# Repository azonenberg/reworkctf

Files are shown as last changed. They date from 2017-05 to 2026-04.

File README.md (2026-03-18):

# reworkctf

## What is it?

This is a points-based challenge board intended for practicing of PCB rework and circuit editing skills. This is not a circuit *debug* challenge. The defect for each stage is well documented, your task is to correct it so that the circuit functions properly.

This is also not a learn-to-solder kit. If you're not comfortable populating boards with 0402 passives and larger pitch (0.8mm) BGAs, this is probably not a project you want to undertake until you have the basics down first.

That said, the challenges range from very easy to fairly difficult, so it's totally fine to try some of them then put the board on a shelf for a while until your skills improve. Inner layer circuit edits are among the most challenging rework tasks around, there's a reason they're worth the most points!

This is also intended to be a relatively low-cost board so you can practice without the pressure of reworking a production design with a big FPGA and five-digit price tag. If you destroy a couple of these boards then get the hang of things and your third attempt succeeds, great - you've learned something.

And if the board survives, you've got a STM32H750 dev platform with a UART, two PMODs, a SPI flash, and a lot of LEDs to maybe do something useful with.

IMPORTANT NOTE: Read the challenge list before populating the front side of the PCB. Some of the BGA-site challenges have two versions, an "easy" version which can be done on a bare PCB before populating allowing easy access to the BGA footprint, and a "hard" version which requires you populate the board before doing the rework. Unless you want to do the hard version twice, don't populate the board until you've done the easier ones. This does require doing some of the challenges out of order, unless you want to make two boards and do different challenges on each.

Most notably, the following challenges should be done before populating the BGA:
* Challenge 13

## How do I complete a given challenge?

It's up to you, within reason. If you are able to restore the intended electrical connectivity to the point that the firmware lights up the corresponding "complete" LED and you've followed any restrictions listed in the problem text, you've done it. Please follow the spirit of the challenges, many of them can be "cheated" by jumpering adjacent pins on the MCU together or similar but the point of this board is skill development. If you don't actually fix the intended defect you're not learning.

Almost all challenges are electrically testable by the MCU firmware; those that involve soldermask or silkscreen rework can be graded by visual inspection of the board. If those look good, they probably are.

The [IPC rework guides](https://www.circuitrework.com/guides/guides.html) are a good starting point for general repair techniques.

If you get really stuck on a specific challenge you can message me on Mastodon at[@azonenberg@ioc.exchange](https://ioc.exchange/@azonenberg]) but please make a reasonable attempt to plan a solution first.

## I still have an old rev board, where's the info for that?

The legacy revision 1 challenge, built around a Spartan-3A FPGA, can be found in the "v1" directory and is being kept there in case anybody has an old board and wants to refer to the design. Anyone building the challenge now should use the v2 design which is based on parts that (as of this writing in early 2026) are readily available and inexpensive.

## What tools are required?

A fine point soldering iron, good tweezers, and hot air rework station are a must to attempt any of the challenges. A stereo microscope is strongly recommended.

The silkscreen and solder mask repair challenges require UV or heat cured coating materials and a curing lamp or oven appropriate for the coating chemistry. UV resin allows much more rapid iteration and avoids heat stress on the remainder of the system so we strongly recommend it over heat cure systems.

Surface trace cuts and rerouting require a scalpel or rotary tool/mill with very fine cutters. While the inner layer circuit edits are *possible* to complete with hand scraping or a handheld rotary tool, we strongly recommend use of a 3-axis mill and microscope for the highest grade results and greatest chance of success.

## What are the challenges?

See [the list here](/CHALLENGES.md). Each challenge is marked with silkscreened text on the PCB to make it easy to find.

## What is the "Free Play Area"?

A big pile of component footprints and traces not connected to anything else. Invent your own challenges or use it to practice for the official ones.

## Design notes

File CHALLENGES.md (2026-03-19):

# ReworkCTF challenge list

## Silkscreen / Solder Mask

These challenges are not electronically gradeable, so they're numbered separately from the others (with a SM- prefix).

### SM-1 (100 points)

Oops, we forgot to label the debug connector! Mark it "JTAG" in white ink.

### SM-2 (100 points)

There's a big hole in the soldermask on the back of the board. Don't ask how it got there, just fix it.

## Surface Conductor

### Challenge 01 (100 points)

A dust speck landed on a photomask and caused a small dot of copper to short the signal trace to the adjacent ground. Clear the short.

### Challenge 02 (200 points)

An etch defect caused two signal traces to short to each other. Clear the short.

### Challenge 08 (100 points)

Somebody dropped a heavy tool on the board and gouged out a short segment from a trace. Reconnect the missing piece.

## Multilayer Conductor / Via

### Challenge 09 (400 points)

We swapped a differential pair for easier layout and didn't realize the SERDES macro didn't have a polarity swap bit. If that wasn't bad enough, it's on an internal layer.

Swap the pair.

(You must do an inner layer circuit edit for this problem. The BGA breakout traces and vias are out of scope.)

### Challenge 10 (300 points)

Somehow we forgot a via between the top and bottom layer. Restore the connection.

### Challenge 11 (400 points)

A zone fill got screwed up and a via from front to back is shorted to the power plane. Clear the short but preserve the intended connection.

(You must do an inner layer circuit edit for this problem, bypassing the via or isolating the zone fill is not allowed.)

### Challenge 15 (100 points)

Somebody forgot a pullup on an open-drain signal. Add a 10K resistor from the trace to the 3V3 rail.

## SMT Component

### Challenge 03 (100 points)

Whoops, one of the LEDs was put on with reversed polarity. Flip it.

### Challenge 04 (200 points)

Place an 10K ohm 0201 resistor on the provided footprint.

### Challenge 05 (300 points)

Place an 10K ohm 01005 resistor on the provided footprint.

### Challenge 06 (200 points)

The intern who made our SOIC flash footprint forgot to put a soldermask aperture on one of the pins! Remove the component, clear the soldermask off the pad, and reconnect the flash.

NOTE: The challenge 6 status LED will not illuminate unless challenge 7 has also been completed.

### Challenge 07 (300 points)

While our previous technician was doing challenge 6, they got too aggressive desoldering and lifted a pad. Install a new pad on the board and restore connectivity to the pin.

NOTE: The challenge 7 status LED will not illuminate unless challenge 6 has also been completed.

## BGA

### Challenge 12 (300 points)

Our solder paste is expired and two balls didn't get good paste coverage so they're not making good contact. Fix it.

(A test point is provided to allow electrical measurements of the test signal)

### Challenge 13 (400 points)

Our BGA breakout generator script had a bug and one of the BGA breakout vias is missing a dogbone trace. Luckily, we discovered the problem BEFORE populating the board, so you have easy access to the BGA site.

### Challenge 14 (500 points)

This is the same exact defect as challenge 13, except somehow it went unnoticed until the board was populated. Have fun.

### Challenge 16 (500 points)

Pin R16 of the MCU should have been strapped to 3V3 but was instead connected to ground. Reconnect the via to the correct plane.

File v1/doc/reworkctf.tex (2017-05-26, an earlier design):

\documentclass{article}
\usepackage[bookmarks,colorlinks=true,linkcolor=blue,urlcolor=blue]{hyperref}
\usepackage{url}
\usepackage{tabularx}
\usepackage{graphicx}
\usepackage{placeins}

\setcounter{tocdepth}{2}

\begin{document}

\title{\vspace*{\fill}PCB Rework CTF}
\author{Andrew Zonenberg\\
azonenberg@drawersteak.com}
\date{\today}

\maketitle
\begin{abstract}
The ``Rework CTF" is a game/training aid, similar to an infosec challenge-based CTF, but focusing on PCB rework and
soldering skills. The intended focus is on technician skills (fixing defects) not engineering skills (finding defects).
The game is intended to be played on fully populated boards; the provided FPGA bitstream will automatically grade most
problems and light up an LED upon successful completion. Additional blank boards may be used for practice and
instruction before a for-point challenge is attempted on a populated PCB.
\end{abstract}
\thispagestyle{empty}

\pagebreak

\tableofcontents

\pagebreak
\section{Introduction}

The bugs are sorted by difficulty, ranging from 100 to 500 points. Any and all tools are in scope, however cheating by
simply shorting the LEVELx\_OK signal to power is not allowed. Specific rules, if applicable, are described in the
subsections for each bug.

Signals related to each bug are prefixed with ``LEVELx\_" in the KiCAD design files to make the bugs easier to find.

There are two kinds of bugs in this board. Electrical connectivity bugs have numeric level identifiers (1, 2, 3, etc).
The corresponding LED will light up when these problems are successfully completed. Mechanical/visual bugs have
alphabetical level identifiers (A, B, C, etc). These are graded by looking at the board and deciding if it looks OK.

All design files, including the Verilog source for the grader bitstream, are available under a 3-clause BSD-style
license.

\pagebreak
\section{100-Point Bugs}

\subsection{Level 1}

Input to a SOIC-packaged 7404 is shorted to the adjacent Vdd. Clear the short.

\subsection{Level 2}

LED-drive enable is always high, but the LED itself was installed backwards, Use hot air to flip it around.

\subsection{Level 3}

Input pad on a SOIC-packaged 7404 footprint is missing. Restore the open connection and install the IC. (50 bonus
points for style if you put in a new SMT pad rather than just running a jumper.)

\subsection{Level 4}

0805 resistor is missing soldermask apertures. Remove the mask and solder a low-valued (anything under 1K should be fine)
resistor onto the pads.

\subsection{Level A}

The resistor you installed in level 4 doesn't have a refdes. Label it ``R30" with white ink.

\subsection{Level B}

A region of the board is missing some solder mask. Mix up some 2-part epoxy, tint it to match the existing mask, and
brush it on.

\pagebreak
\section{200-Point Bugs}

\subsection{Level 5}

Tiny short circuit between two closely spaced signals. Clear the short without damaging either line.

\subsection{Level 6}

Large short circuit between two closely spaced signals. Clear the short without damaging either line.

\subsection{Level 7}

LVDS pair on outer layer with P/N swapped. Hook them up correctly.

\subsection{Level 8}

Several pads on a TSSOP-packaged 7404 footprint are missing. Restore the open connection and install the IC. (50
bonus points for style if you put in a new SMT pad rather than just running a jumper.)

\subsection{Level 9}

Install an 01005 resistor (anything under 1K should be fine) onto the provided pads.

\subsection{Level 10}

Via connecting to input of TSSOP-packaged 7404 doesn't actually connect to the input. Fix it.

\subsection{Level 11}

Missing thermal relief connecting to one side of an 0201 passive causing tombstoning. Cut out a thermal relief and fix
the tombstoned part.

\pagebreak
\section{300-Point Bugs}

\subsection{Level 12}

A through-board via wasn't drilled. Fix it.

\subsection{Level 13}

Two signals on an internal layer are shorted. Clear the short.

\subsection{Level 14}

A dogbone via on the FPGA footprint wasn't connected to the corresponding ball. Fix it before installing the FPGA.

\pagebreak
\section{400-Point Bugs}

\subsection{Level 15}

A differential pair on an internal layer is swapped. Fix it. For this level, you're not allowed to just drill out the
trace and connect the vias directly, we're pretending the vias are blind/buried. You must fix this with an inner-layer
circuit edit.

\subsection{Level 16}

Two signals on an internal layer are shorted together. Clear the short. Heavy routing congestion on the top layer
make this harder than level 13.

\subsection{Level 17}

Due to a drill-gerber file version mismatch, a signal via was shorted to the internal ground plane. Clear the short.

\subsection{Level 18}

A dogbone via on the FPGA footprint wasn't drilled out. Fix it before installing the FPGA.

\pagebreak
\section{500-Point Bugs}

\subsection{Level 19}

Two blind vias at the same place on opposite sides of the board were incorrectly drilled as a through-board via.
Separate the two vias so that the outer layers connect to the adjacent plane, but they don't short to each other.

\subsection{Level 20}

A strap pin under a BGA was incorrectly tied high. Pull it low instead.

\subsection{Level 21}

Two signals on an internal layer are shorted together. Clear the short. Heavy routing congestion on both outer layers
make this harder than level 16.

\subsection{Level 22}

A dogbone via on the FPGA footprint wasn't drilled out. Fix it after installing the FPGA.

\subsection{Level 23}

I put 22 intentional bugs in this board. Can you find a 23rd? If so, there's a spot marked for you to install another
LED. You've earned it!

\pagebreak
\section{Extra-credit problems}

\subsection{Level 24}

Put a TSSOP-packaged 74HC04 onto the SOIC footprint, or vice versa.

\subsection{TODOs for next version}

TODOs for next version: mirrored IC footprints, holes too small for PTH component

\end{document}

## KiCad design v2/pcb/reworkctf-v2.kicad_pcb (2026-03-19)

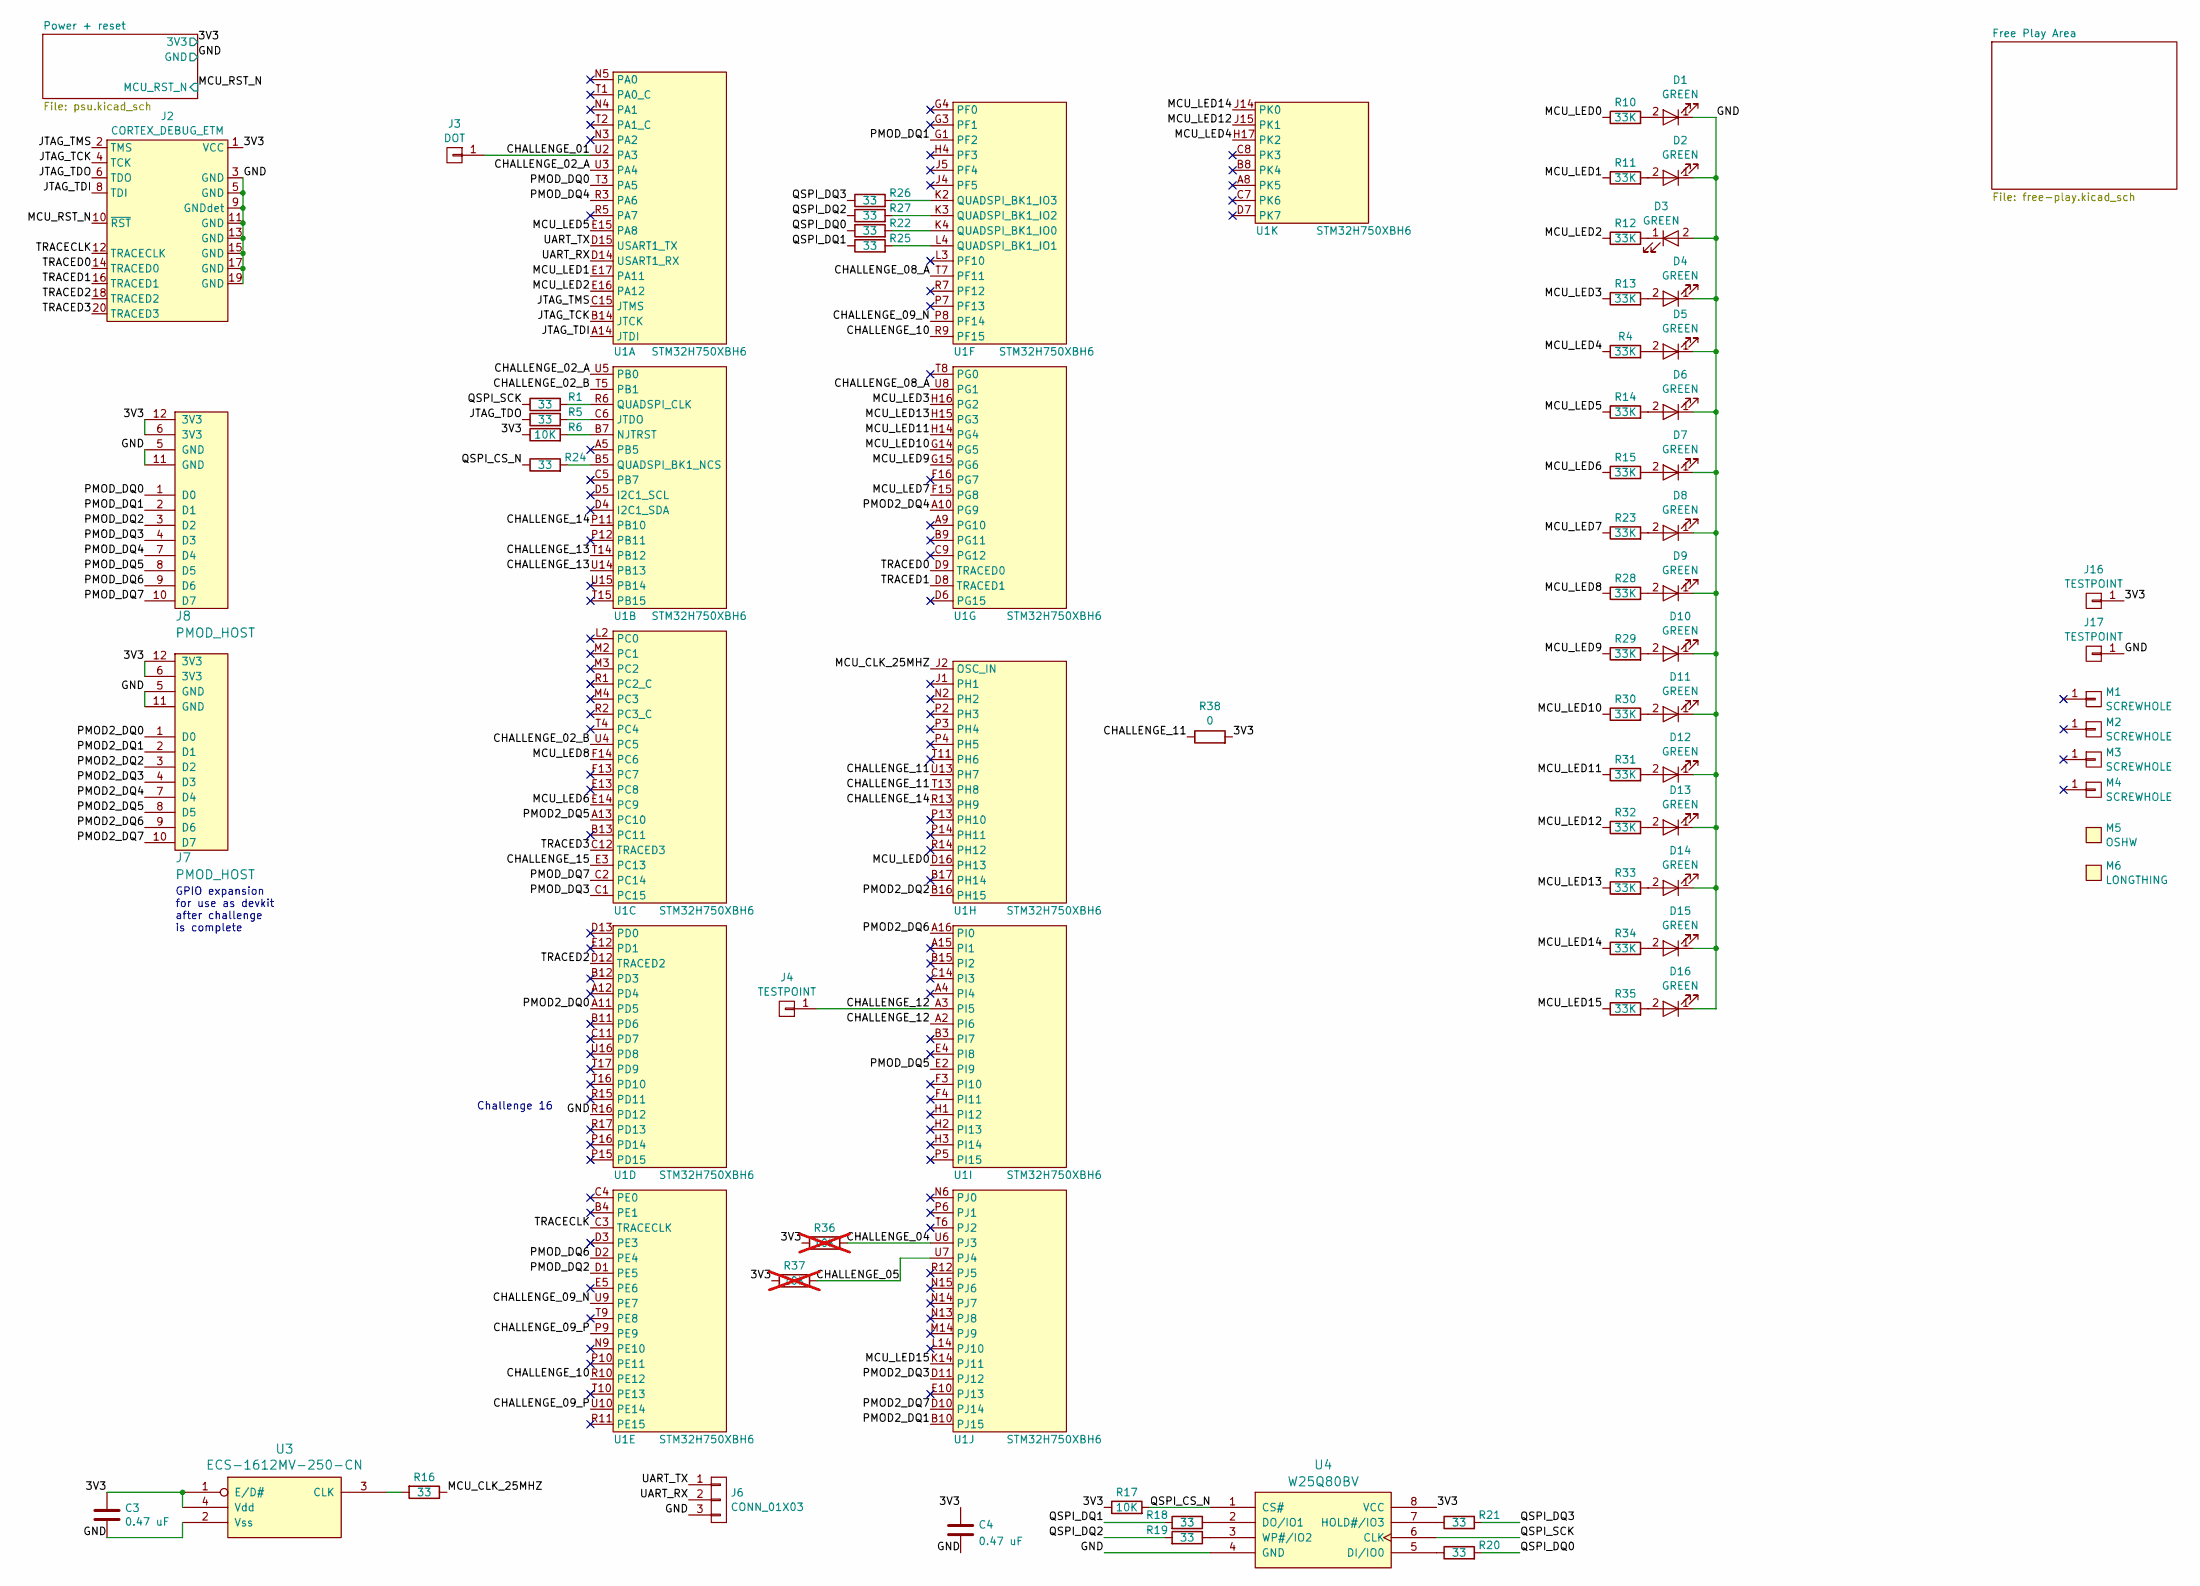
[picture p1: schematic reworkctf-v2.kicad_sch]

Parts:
C3, C4: 0.47 uF; EIA_0402_CAP_NOSILK
D1, D2, D3, D4, D5, D6, D7, D8, D9, D10, D11, D12, D13, D14, D15, D16: GREEN; EIA_0402_LED
J2: CORTEX_DEBUG_ETM; CONN_HEADER_1.27MM_2x10_SMT_SAMTEC_FTSH-110-01-L-DV-K
J3: DOT; TESTPOINT_SMT_0.5MM
J4, J16, J17: TESTPOINT; TESTPOINT_SMT_0.5MM
J6: CONN_01X03; CONN_HEADER_2.54MM_1x3_REFLOW
J7, J8: PMOD_HOST; CONN_HEADER_2.54MM_2x6_RA_PMOD_HOST
M1, M2, M3, M4: SCREWHOLE; MECHANICAL_CLEARANCEHOLE_4_40
M5: OSHW; Logo_silk_OSHW_6x6mm
M6: LONGTHING; LONGTHING-1200DPI
R1, R5, R16, R18, R19, R20, R21, R22, R24, R25, R26, R27: 33; EIA_0402_RES_NOSILK
R4, R10, R11, R12, R13, R14, R15, R23, R28, R29, R30, R31, R32, R33, R34, R35: 33K; EIA_0402_RES_NOSILK
R6, R17: 10K; EIA_0402_RES_NOSILK
R36: 10K; EIA_0201_RES_NOSILK; not fitted
R37: 10K; EIA_01005_RES_NOSILK; not fitted
R38: 0; EIA_0402_RES_NOSILK
U1: STM32H750XBH6; BGA_265_14x14_DEPOP_0.8MM
U3: ECS-1612MV-250-CN; OSCILLATOR_1.6x1.2
U4: W25Q80BV; SOIC_8_5.3MM

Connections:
/3V3: C3.1, C4.1, J2.1 (VCC), J7.6 (3V3), J7.12 (3V3), J8.6 (3V3), J8.12 (3V3), J16.1, R6.1, R17.1, R36.1, R37.1, R38.2, U3.1 (E/D#), U3.4 (Vdd), U4.8 (VCC); also elsewhere on the board
/CHALLENGE_01: J3.1, U1.U2 (PA3)
/CHALLENGE_02_A: U1.U3 (PA4), U1.U5 (PB0)
/CHALLENGE_02_B: U1.T5 (PB1), U1.U4 (PC5)
/CHALLENGE_04: R36.2, U1.U6 (PJ3)
/CHALLENGE_05: R37.2, U1.U7 (PJ4)
/CHALLENGE_08_A: U1.T7 (PF11), U1.U8 (PG1)
/CHALLENGE_09_N: U1.P8 (PF14), U1.U9 (PE7)
/CHALLENGE_09_P: U1.P9 (PE9), U1.U10 (PE14)
/CHALLENGE_10: U1.R9 (PF15), U1.R10 (PE12)
/CHALLENGE_11: R38.1, U1.T13 (PH8), U1.U13 (PH7)
/CHALLENGE_12: J4.1, U1.A2 (PI6), U1.A3 (PI5)
/CHALLENGE_13: U1.T14 (PB12), U1.U14 (PB13)
/CHALLENGE_14: U1.P11 (PB10), U1.R13 (PH9)
/CHALLENGE_15: U1.E3 (PC13)
/GND: C3.2, C4.2, D1.1 (K), D2.1 (K), D3.2 (A), D4.1 (K), D5.1 (K), D6.1 (K), D7.1 (K), D8.1 (K), D9.1 (K), D10.1 (K), D11.1 (K), D12.1 (K), D13.1 (K), D14.1 (K), D15.1 (K), D16.1 (K), J2.3 (GND), J2.5 (GND), J2.9 (GNDdet), J2.11 (GND), J2.13 (GND), J2.15 (GND), J2.17 (GND), J2.19 (GND), J6.3, J7.5 (GND), J7.11 (GND), J8.5 (GND), J8.11 (GND), J17.1, U1.R16 (PD12), U3.2 (Vss), U4.4 (GND); also elsewhere on the board
/JTAG_TCK: J2.4 (TCK), U1.B14 (JTCK)
/JTAG_TDI: J2.8 (TDI), U1.A14 (JTDI)
/JTAG_TDO: J2.6 (TDO), R5.1
/JTAG_TMS: J2.2 (TMS), U1.C15 (JTMS)
/MCU_CLK_25MHZ: R16.1, U1.J2 (OSC_IN)
/MCU_LED0: R10.1, U1.D16 (PH13)
/MCU_LED1: R11.1, U1.E17 (PA11)
/MCU_LED2: R12.1, U1.E16 (PA12)
/MCU_LED3: R13.1, U1.H16 (PG2)
/MCU_LED4: R4.1, U1.H17 (PK2)
/MCU_LED5: R14.1, U1.E15 (PA8)
/MCU_LED6: R15.1, U1.E14 (PC9)
/MCU_LED7: R23.1, U1.F15 (PG8)
/MCU_LED8: R28.1, U1.F14 (PC6)
/MCU_LED9: R29.1, U1.G15 (PG6)
/MCU_LED10: R30.1, U1.G14 (PG5)
/MCU_LED11: R31.1, U1.H14 (PG4)
/MCU_LED12: R32.1, U1.J15 (PK1)
/MCU_LED13: R33.1, U1.H15 (PG3)
/MCU_LED14: R34.1, U1.J14 (PK0)
/MCU_LED15: R35.1, U1.K14 (PJ11)
/MCU_RST_N: J2.10 (~RST); also elsewhere on the board
/PMOD2_DQ0: J7.1 (D0), U1.A11 (PD5)
/PMOD2_DQ1: J7.2 (D1), U1.B10 (PJ15)
/PMOD2_DQ2: J7.3 (D2), U1.B16 (PH15)
/PMOD2_DQ3: J7.4 (D3), U1.D11 (PJ12)
/PMOD2_DQ4: J7.7 (D4), U1.A10 (PG9)
/PMOD2_DQ5: J7.8 (D5), U1.A13 (PC10)
/PMOD2_DQ6: J7.9 (D6), U1.A16 (PI0)
/PMOD2_DQ7: J7.10 (D7), U1.D10 (PJ14)
/PMOD_DQ0: J8.1 (D0), U1.T3 (PA5)
/PMOD_DQ1: J8.2 (D1), U1.G1 (PF2)
/PMOD_DQ2: J8.3 (D2), U1.D1 (PE5)
/PMOD_DQ3: J8.4 (D3), U1.C1 (PC15)
/PMOD_DQ4: J8.7 (D4), U1.R3 (PA6)
/PMOD_DQ5: J8.8 (D5), U1.E2 (PI9)
/PMOD_DQ6: J8.9 (D6), U1.D2 (PE4)
/PMOD_DQ7: J8.10 (D7), U1.C2 (PC14)
/QSPI_CS_N: R17.2, R24.1, U4.1 (CS#)
/QSPI_DQ0: R20.2, R22.1
/QSPI_DQ1: R18.2, R25.1
/QSPI_DQ2: R19.2, R27.1
/QSPI_DQ3: R21.2, R26.1
/QSPI_SCK: R1.1, U4.6 (CLK)
/TRACECLK: J2.12 (TRACECLK), U1.C3 (TRACECLK)
/TRACED0: J2.14 (TRACED0), U1.D9 (TRACED0)
/TRACED1: J2.16 (TRACED1), U1.D8 (TRACED1)
/TRACED2: J2.18 (TRACED2), U1.D12 (TRACED2)
/TRACED3: J2.20 (TRACED3), U1.C12 (TRACED3)
/UART_RX: J6.2, U1.D14 (USART1_RX)
/UART_TX: J6.1, U1.D15 (USART1_TX)
unnamed: D1.2 (A), R10.2
unnamed: D2.2 (A), R11.2
unnamed: D3.1 (K), R12.2
unnamed: D4.2 (A), R13.2
unnamed: D5.2 (A), R4.2
unnamed: D6.2 (A), R14.2
unnamed: D7.2 (A), R15.2
unnamed: D8.2 (A), R23.2
unnamed: D9.2 (A), R28.2
unnamed: D10.2 (A), R29.2
unnamed: D11.2 (A), R30.2
unnamed: D12.2 (A), R31.2
unnamed: D13.2 (A), R32.2
unnamed: D14.2 (A), R33.2
unnamed: D15.2 (A), R34.2
unnamed: D16.2 (A), R35.2
unnamed: R1.2, U1.R6 (QUADSPI_CLK)
unnamed: R5.2, U1.C6 (JTDO)
unnamed: R6.2, U1.B7 (NJTRST)
unnamed: R24.2, U1.B5 (QUADSPI_BK1_NCS)
unnamed: R26.2, U1.K2 (QUADSPI_BK1_IO3)
unnamed: R27.2, U1.K3 (QUADSPI_BK1_IO2)
unnamed: R22.2, U1.K4 (QUADSPI_BK1_IO0)
unnamed: R25.2, U1.L4 (QUADSPI_BK1_IO1)
unnamed: R16.2, U3.3 (CLK)
unnamed: R20.1, U4.5 (DI/IO0)
unnamed: R18.1, U4.2 (DO/IO1)
unnamed: R21.1, U4.7 (HOLD#/IO3)
unnamed: R19.1, U4.3 (WP#/IO2)

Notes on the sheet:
Challenge 16
GPIO expansion for use as devkit after challenge is complete

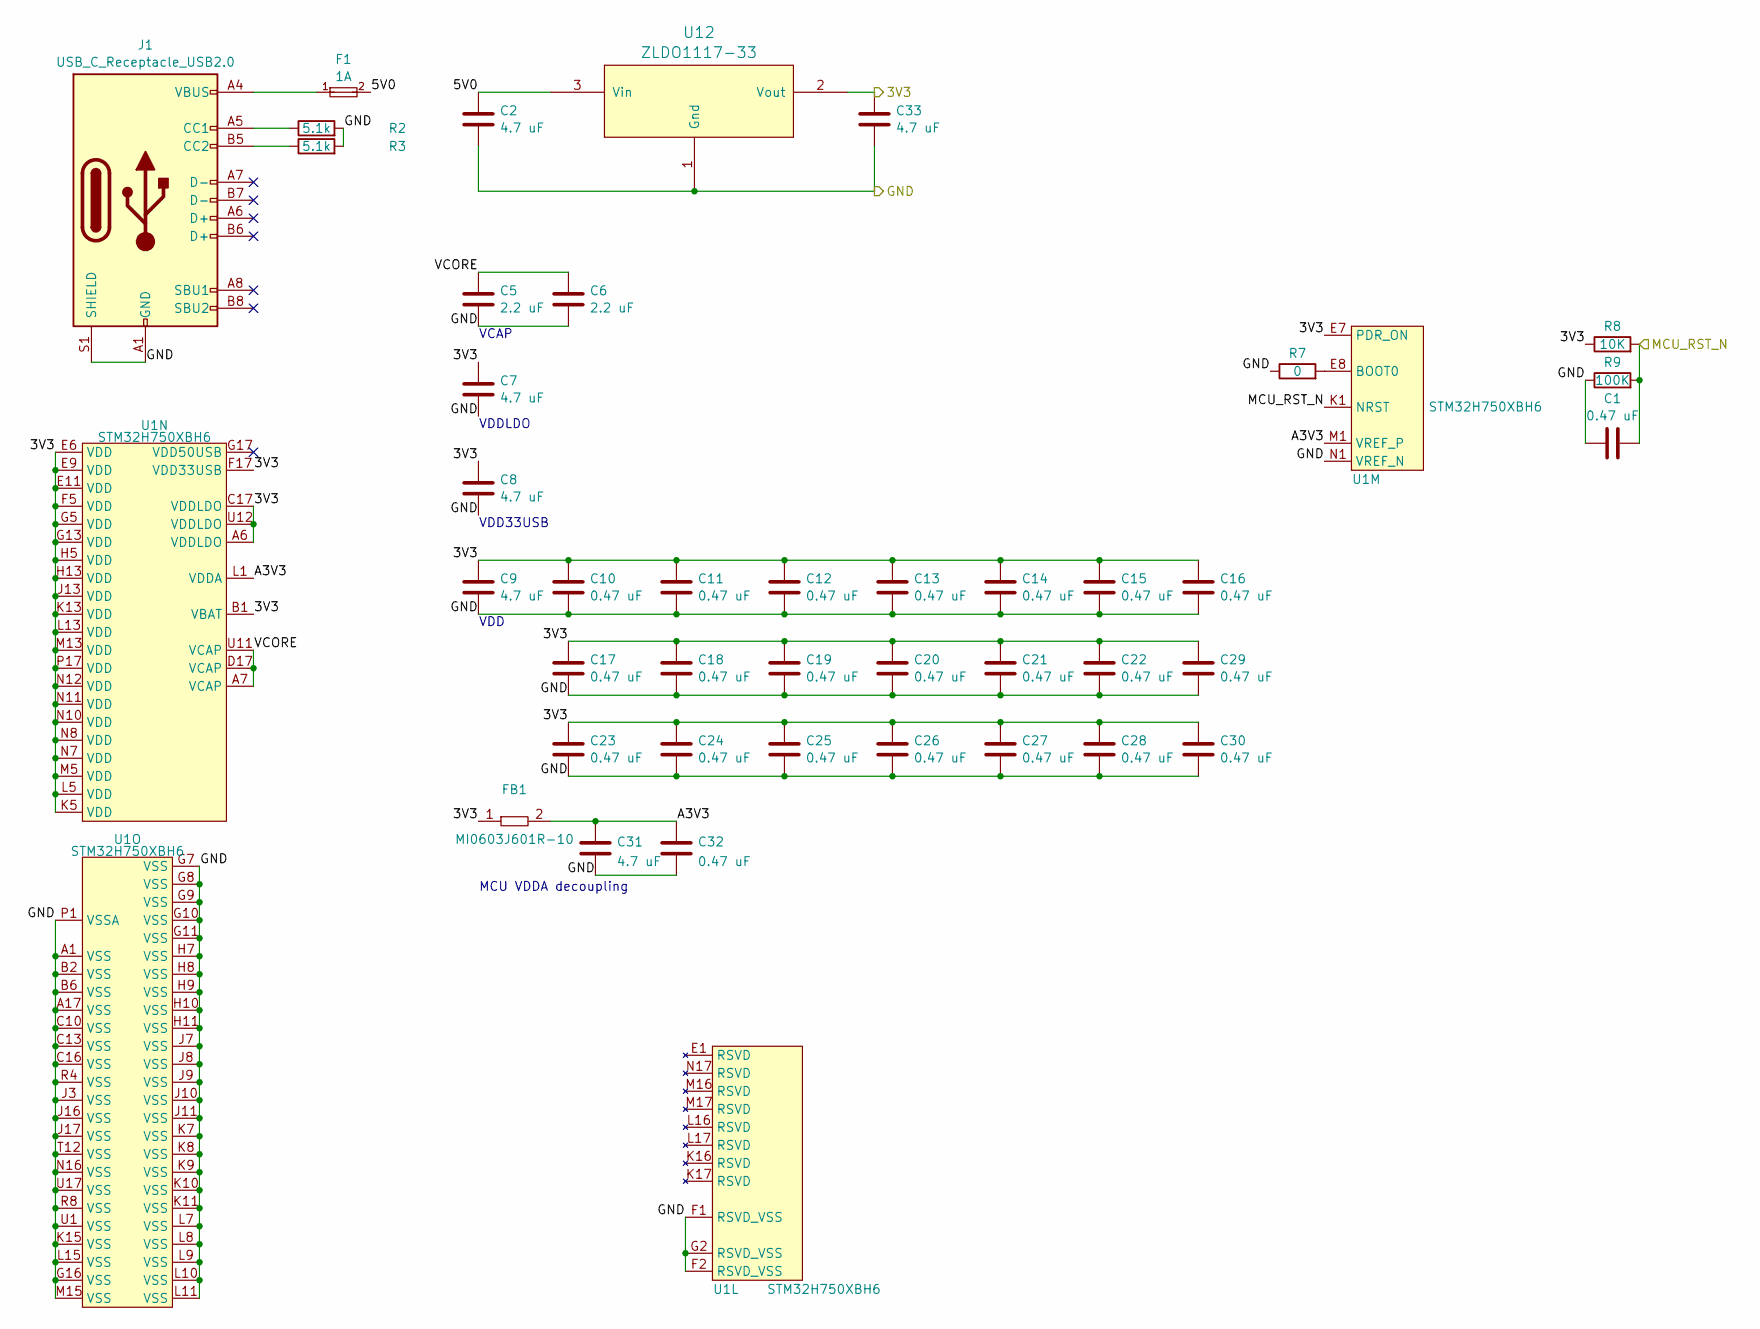
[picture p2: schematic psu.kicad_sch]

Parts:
C1, C10, C11, C12, C13, C14, C15, C16, C17, C18, C19, C20, C21, C22, C23, C24, C25, C26, C27, C28, C29, C30, C32: 0.47 uF; EIA_0402_CAP_NOSILK
C2, C7, C8, C9, C31, C33: 4.7 uF; EIA_0603_CAP_NOSILK
C5, C6: 2.2 uF; EIA_0603_CAP_NOSILK
F1: 1A; EIA_0402_RES_NOSILK
FB1: MI0603J601R-10; EIA_0603_INDUCTOR_NOSILK
J1: USB_C_Receptacle_USB2.0; GCT_USB4500-03-0-A
R2, R3: 5.1k; EIA_0402_RES_NOSILK
R7: 0; EIA_0402_RES_NOSILK
R8: 10K; EIA_0402_RES_NOSILK
R9: 100K; EIA_0402_RES_NOSILK
U1: STM32H750XBH6; BGA_265_14x14_DEPOP_0.8MM
U12: ZLDO1117-33; SOT223-4

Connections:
/3V3: C7.1, C8.1, C9.1, C10.1, C11.1, C12.1, C13.1, C14.1, C15.1, C16.1, C17.1, C18.1, C19.1, C20.1, C21.1, C22.1, C23.1, C24.1, C25.1, C26.1, C27.1, C28.1, C29.1, C30.1, C33.1, FB1.1, R8.1, U1.A6 (VDDLDO), U1.B1 (VBAT), U1.C17 (VDDLDO), U1.E6 (VDD), U1.E7 (PDR_ON), U1.E9 (VDD), U1.E11 (VDD), U1.F5 (VDD), U1.F17 (VDD33USB), U1.G5 (VDD), U1.G13 (VDD), U1.H5 (VDD), U1.H13 (VDD), U1.J13 (VDD), U1.K5 (VDD), U1.K13 (VDD), U1.L5 (VDD), U1.L13 (VDD), U1.M5 (VDD), U1.M13 (VDD), U1.N7 (VDD), U1.N8 (VDD), U1.N10 (VDD), U1.N11 (VDD), U1.N12 (VDD), U1.P17 (VDD), U1.U12 (VDDLDO), U12.2 (Vout); also elsewhere on the board
/GND: C1.1, C2.2, C5.2, C6.2, C7.2, C8.2, C9.2, C10.2, C11.2, C12.2, C13.2, C14.2, C15.2, C16.2, C17.2, C18.2, C19.2, C20.2, C21.2, C22.2, C23.2, C24.2, C25.2, C26.2, C27.2, C28.2, C29.2, C30.2, C31.2, C32.2, C33.2, J1.A1 (GND), J1.A12 (GND), J1.B1 (GND), J1.B12 (GND), J1.S1 (SHIELD), R2.2, R3.2, R7.1, R9.1, U1.A1 (VSS), U1.A17 (VSS), U1.B2 (VSS), U1.B6 (VSS), U1.C10 (VSS), U1.C13 (VSS), U1.C16 (VSS), U1.F1 (RSVD_VSS), U1.F2 (RSVD_VSS), U1.G2 (RSVD_VSS), U1.G7 (VSS), U1.G8 (VSS), U1.G9 (VSS), U1.G10 (VSS), U1.G11 (VSS), U1.G16 (VSS), U1.H7 (VSS), U1.H8 (VSS), U1.H9 (VSS), U1.H10 (VSS), U1.H11 (VSS), U1.J3 (VSS), U1.J7 (VSS), U1.J8 (VSS), U1.J9 (VSS), U1.J10 (VSS), U1.J11 (VSS), U1.J16 (VSS), U1.J17 (VSS), U1.K7 (VSS), U1.K8 (VSS), U1.K9 (VSS), U1.K10 (VSS), U1.K11 (VSS), U1.K15 (VSS), U1.L7 (VSS), U1.L8 (VSS), U1.L9 (VSS), U1.L10 (VSS), U1.L11 (VSS), U1.L15 (VSS), U1.M15 (VSS), U1.N1 (VREF_N), U1.N16 (VSS), U1.P1 (VSSA), U1.R4 (VSS), U1.R8 (VSS), U1.T12 (VSS), U1.U1 (VSS), U1.U17 (VSS), U12.1 (Gnd); also elsewhere on the board
/MCU_RST_N: C1.2, R8.2, R9.2, U1.K1 (NRST); also elsewhere on the board
/Power + reset/5V0: C2.1, F1.2, U12.3 (Vin)
/Power + reset/A3V3: C31.1, C32.1, FB1.2, U1.L1 (VDDA), U1.M1 (VREF_P)
/Power + reset/VCORE: C5.1, C6.1, U1.A7 (VCAP), U1.D17 (VCAP), U1.U11 (VCAP)
unnamed: F1.1, J1.A4 (VBUS), J1.A9 (VBUS), J1.B4 (VBUS), J1.B9 (VBUS)
unnamed: J1.A5 (CC1), R2.1
unnamed: J1.B5 (CC2), R3.1
unnamed: R7.2, U1.E8 (BOOT0)

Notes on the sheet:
VDD
MCU VDDA decoupling
VDDLDO
VCAP
VDD33USB

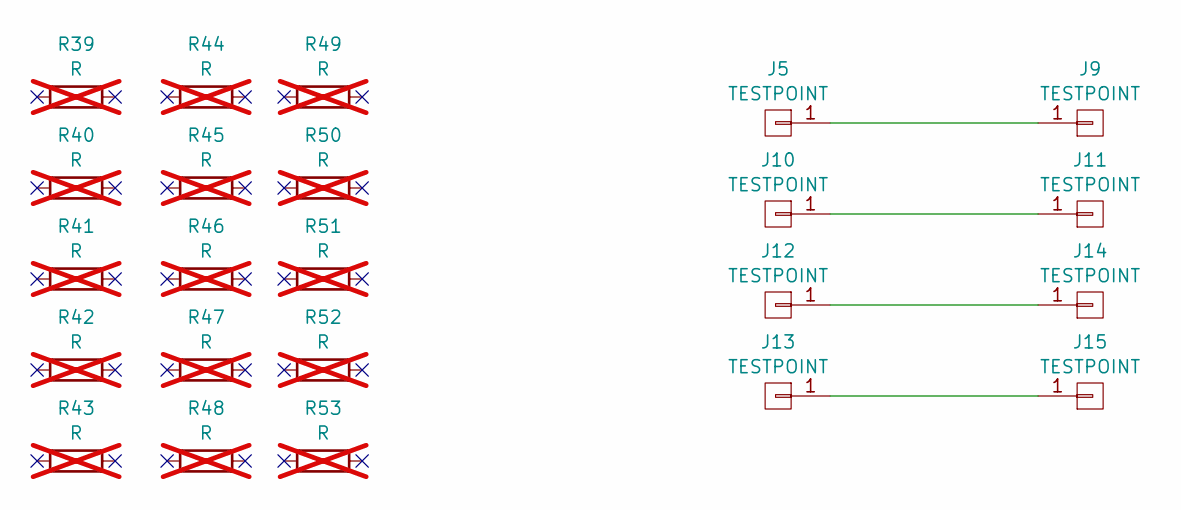
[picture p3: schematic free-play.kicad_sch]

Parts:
J5, J9, J10, J11, J12, J13, J14, J15: TESTPOINT; TESTPOINT_SMT_0.5MM
R39, R40, R41, R42, R43, R44, R45, R46, R47, R48, R49, R50, R51, R52, R53: R; EIA_0402_RES_NOSILK; not fitted

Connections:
unnamed: J5.1, J9.1
unnamed: J10.1, J11.1
unnamed: J12.1, J14.1
unnamed: J13.1, J15.1

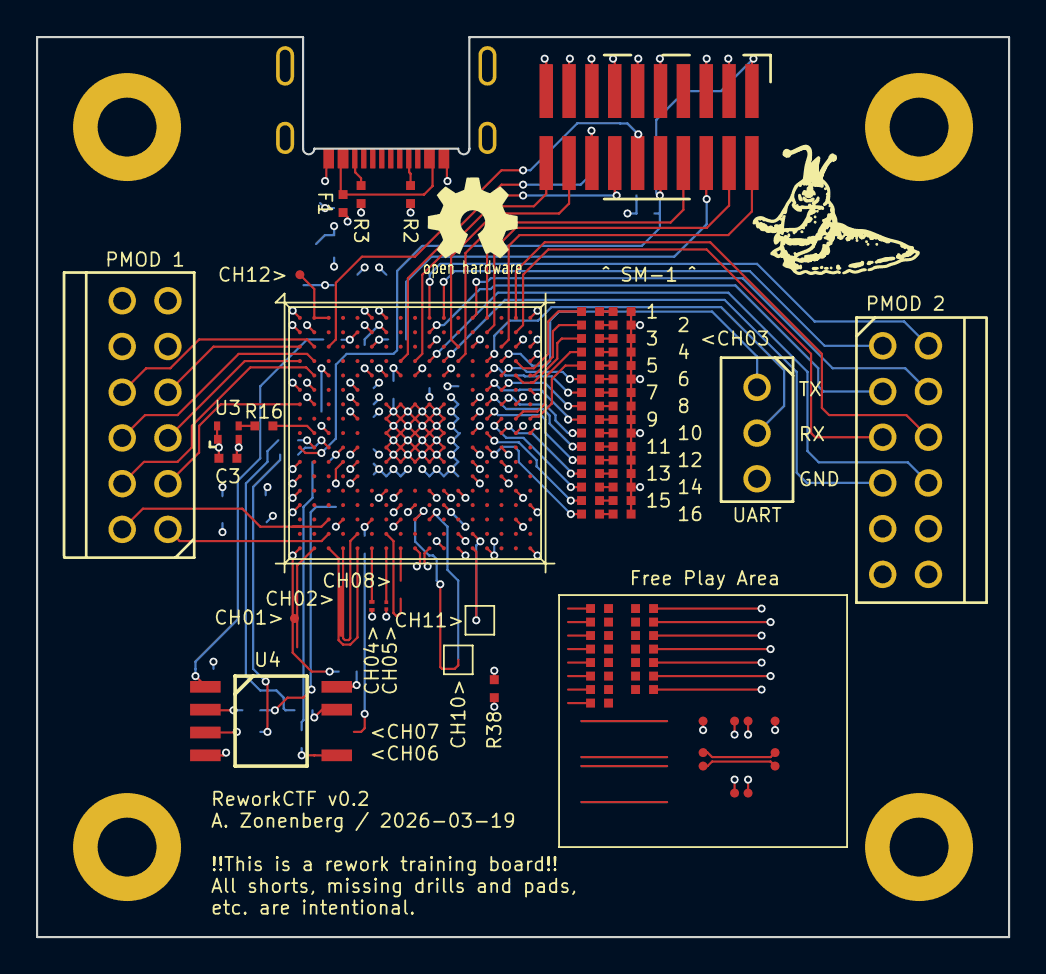
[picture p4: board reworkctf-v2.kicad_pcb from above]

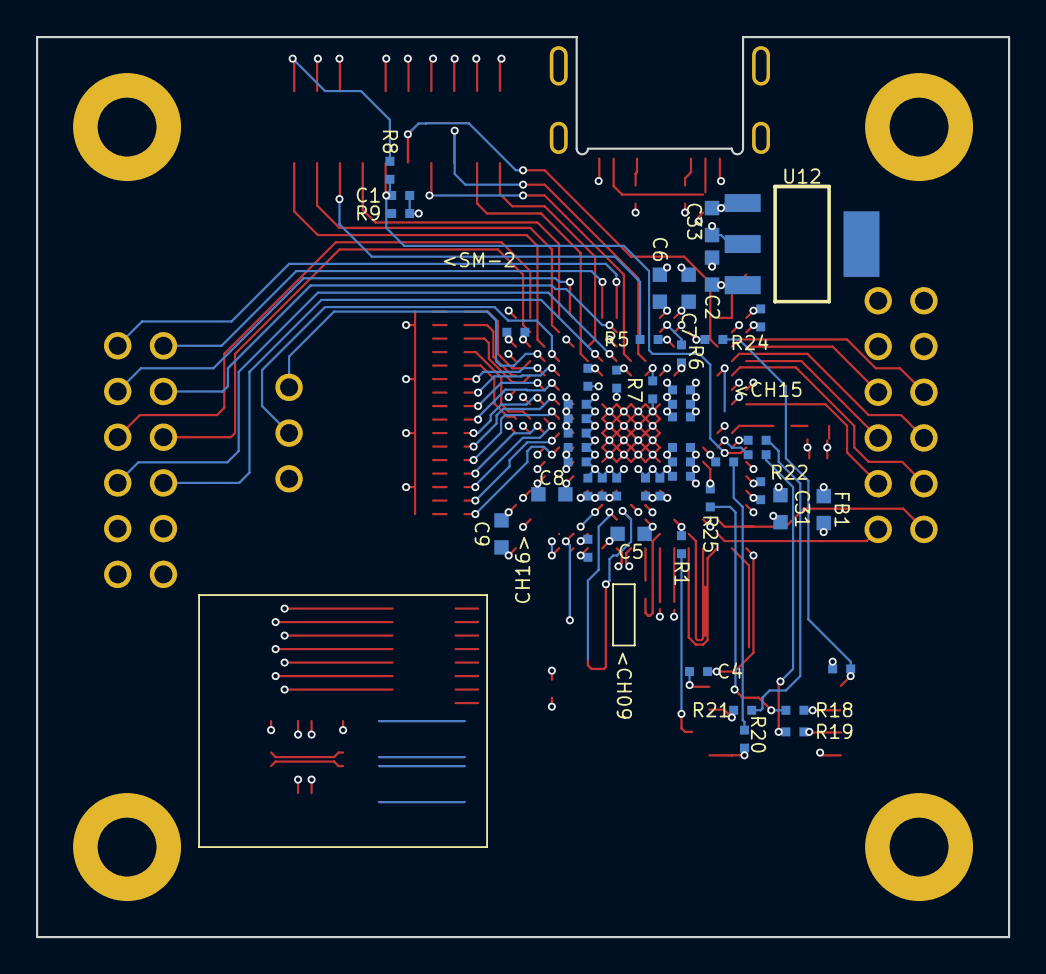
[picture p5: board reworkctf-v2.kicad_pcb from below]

Board: 4 copper layers, 54.0 x 50.0 mm, 131 parts (50 on the bottom side), 105 nets.

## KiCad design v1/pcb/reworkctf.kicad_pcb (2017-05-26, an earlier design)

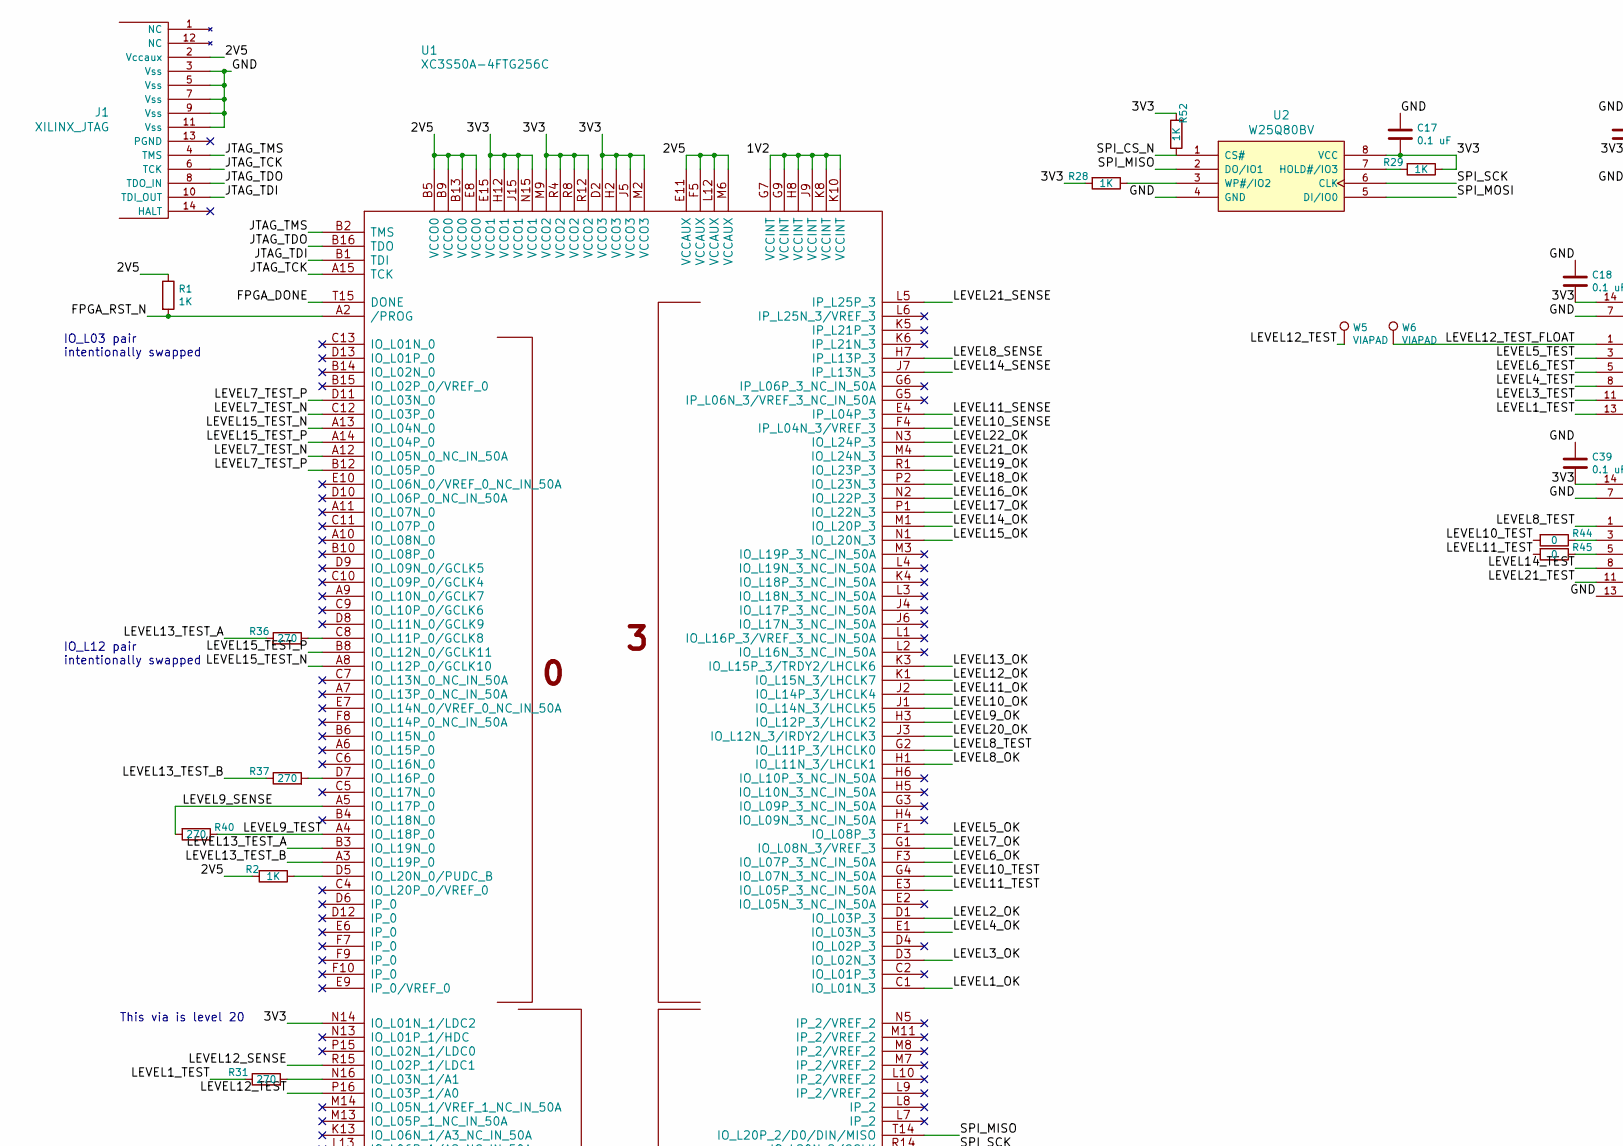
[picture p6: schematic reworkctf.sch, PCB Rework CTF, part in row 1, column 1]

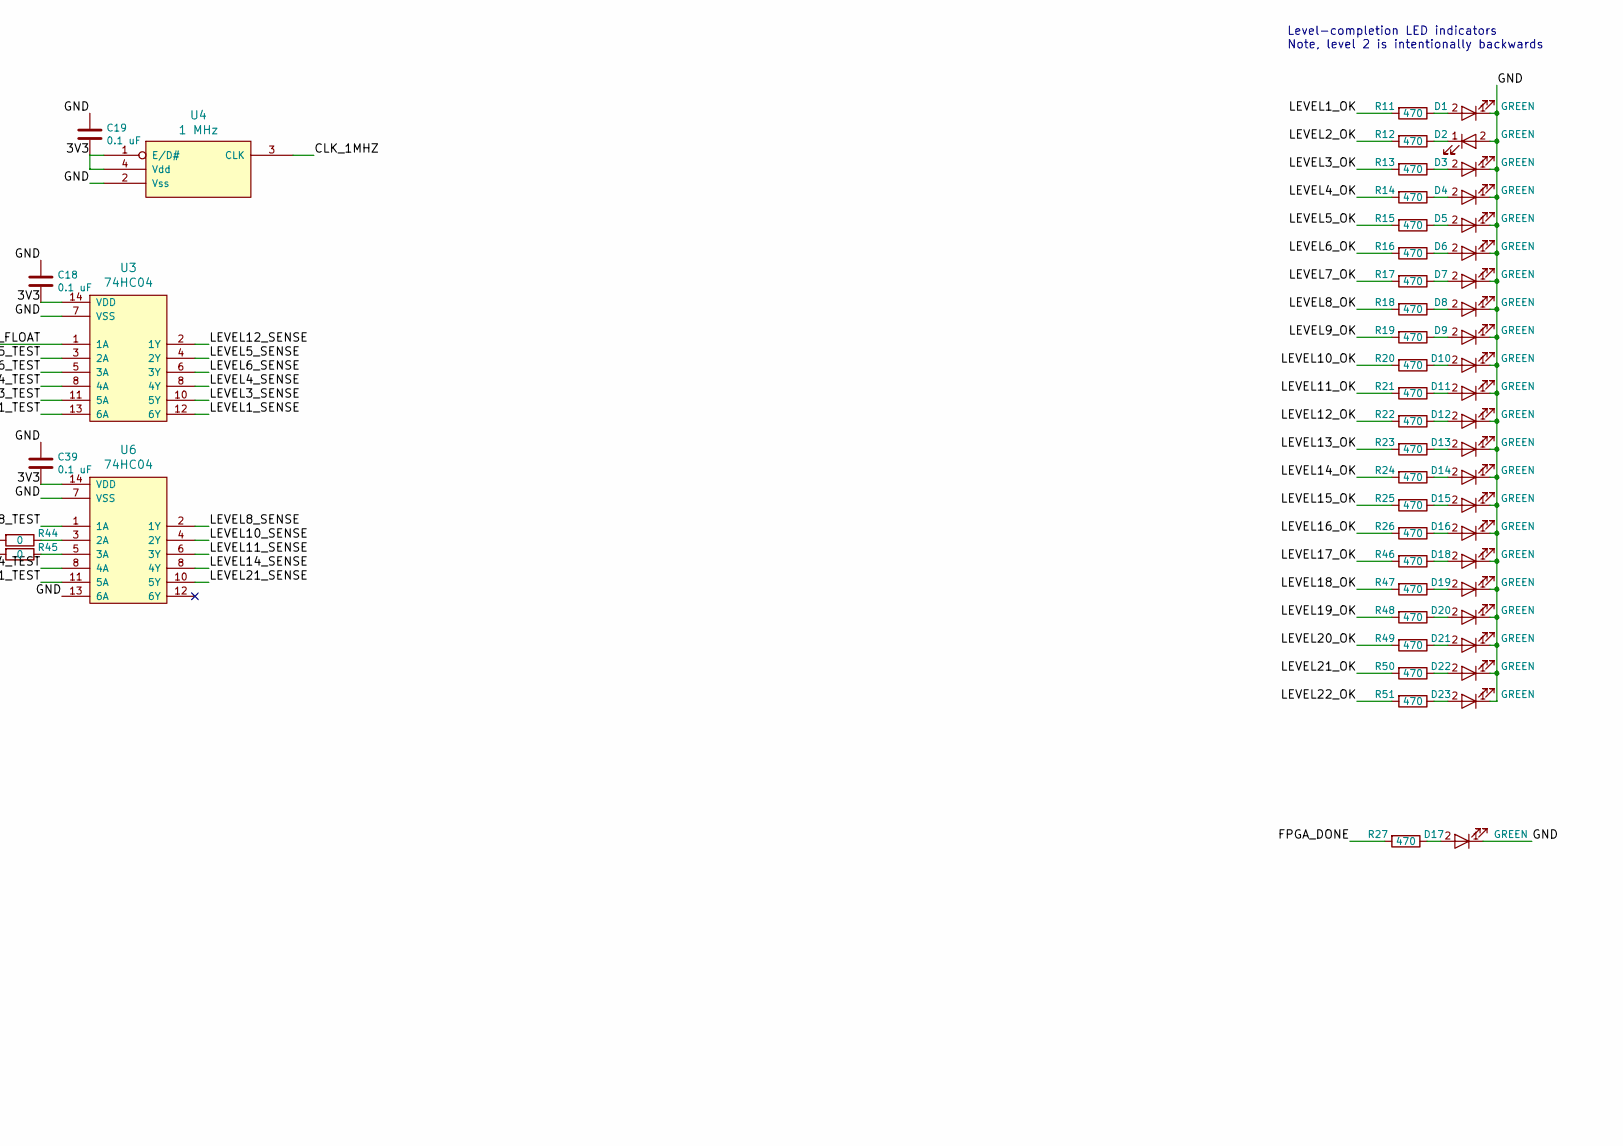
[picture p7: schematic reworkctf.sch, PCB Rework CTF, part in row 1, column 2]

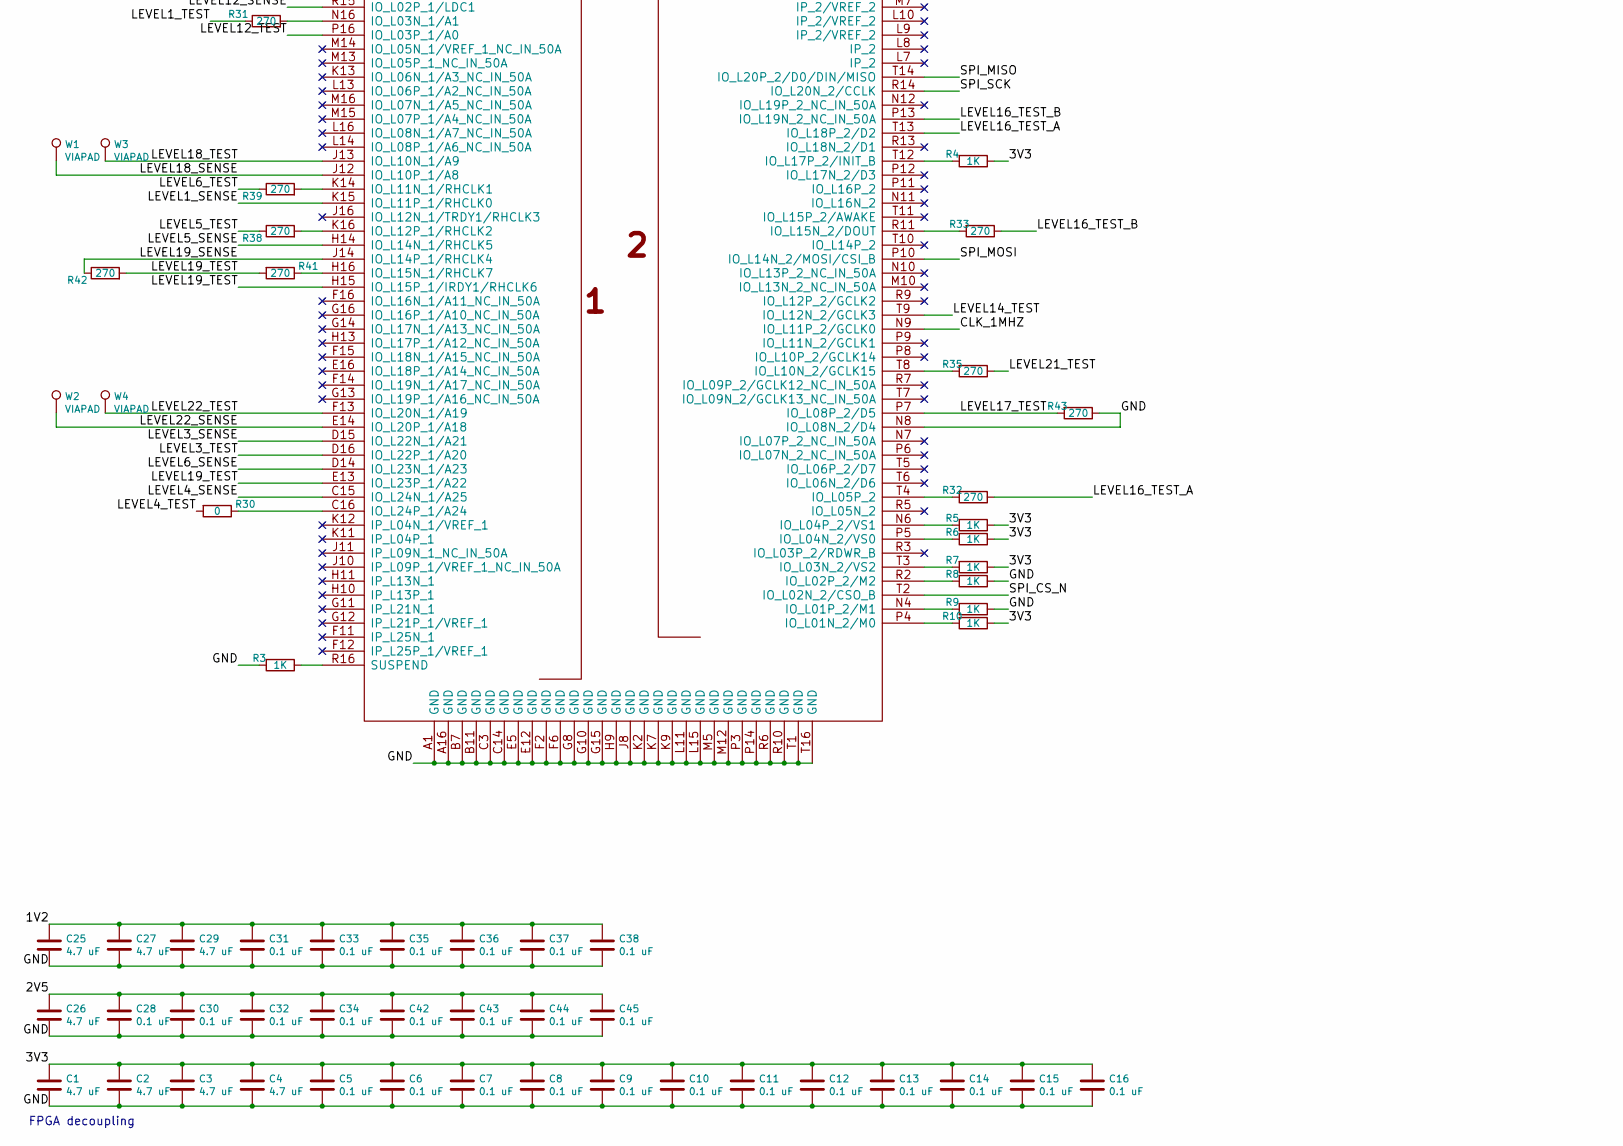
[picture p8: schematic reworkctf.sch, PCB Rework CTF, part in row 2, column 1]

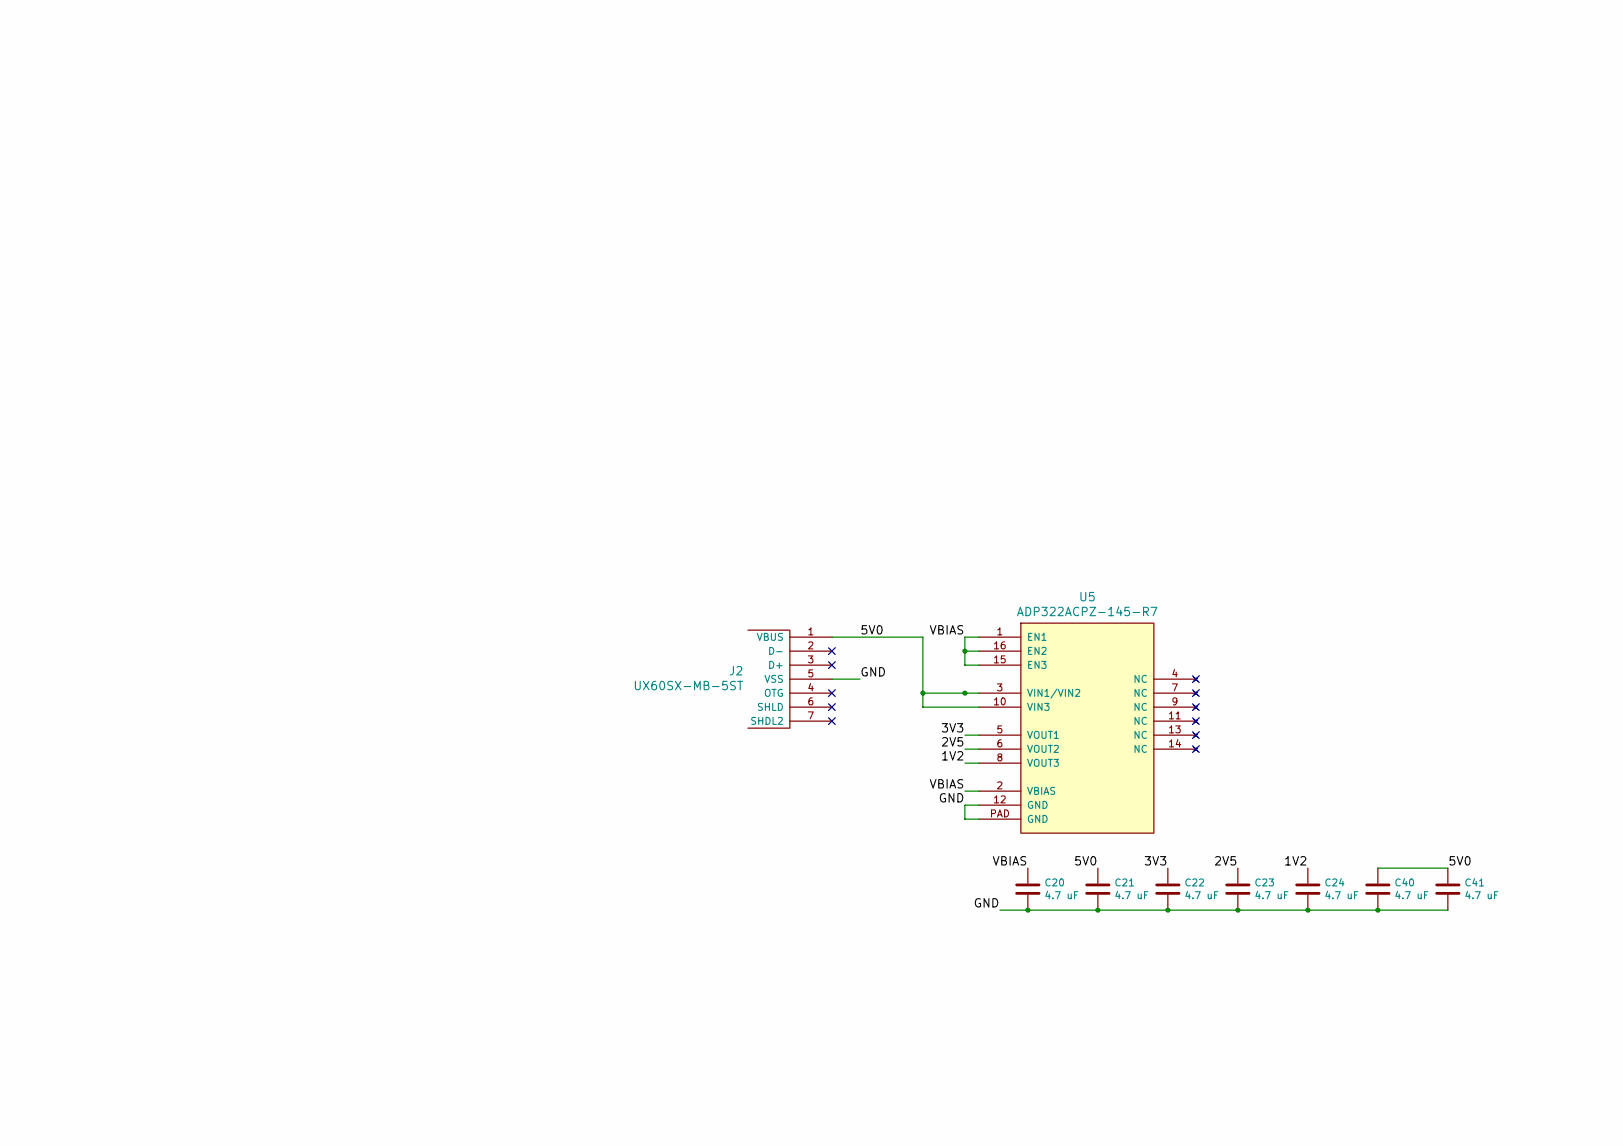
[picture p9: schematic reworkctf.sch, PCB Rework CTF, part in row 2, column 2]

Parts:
C1, C2, C3, C4, C20, C21, C22, C23, C24, C25, C26, C27, C29, C40, C41: 4.7 uF; EIA_0603_CAP_NOSILK
C5, C6, C7, C8, C9, C10, C11, C12, C13, C14, C15, C16, C17, C18, C19, C28, C30, C31, C32, C33, C34, C35, C36, C37, C38, C39, C42, C43, C44, C45: 0.1 uF; EIA_0402_CAP_NOSILK
D1, D2, D3, D4, D5, D6, D7, D8, D9, D10, D11, D12, D13, D14, D15, D16, D17, D18, D19, D20, D21, D22, D23: GREEN; EIA_0603_LED
J1: XILINX_JTAG; XILINX_JTAG_PTH_MOLEX_0878311420
J2: UX60SX-MB-5ST; CONN_HIROSE_UX60S-MB-5ST_MINI_USB
R1, R2, R3, R4, R5, R6, R7, R8, R9, R10, R28, R29, R52: 1K; EIA_0402_RES_NOSILK
R11, R12, R13, R14, R15, R16, R17, R18, R19, R20, R21, R22, R23, R24, R25, R26, R27, R46, R47, R48, R49, R50, R51: 470; EIA_0402_RES_NOSILK
R30: 0; EIA_0805_CAP_NOSILK
R31, R32, R33, R35, R36, R37, R38, R39, R41, R42, R43: 270; EIA_0402_RES_NOSILK
R40: 270; EIA_01005_RES_NOSILK
R44: 0; EIA_0402_RES_NOSILK
R45: 0; EIA_0201_RES_NOSILK
U1: XC3S50A-4FTG256C; BGA_256_17x17_FULLARRAY_1MM
U2: W25Q80BV; SOIC_8_3.9MM
U3: 74HC04; SOIC_14_3.9MM_NOPIN11
U4: 1 MHz; OSCILLATOR_3.2x2.5
U5: ADP322ACPZ-145-R7; QFN_16_0.5MM_3x3MM
U6: 74HC04; TSSOP_14_0.65MM_5p6MM_NOPINS_1_2
W1, W2, W3, W4, W5, W6: VIAPAD; TESTPOINT_SMT_0.5MM

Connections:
/1V2: C24.1, C25.1, C27.1, C29.1, C31.1, C33.1, C35.1, C36.1, C37.1, C38.1, U1.G7 (VCCINT), U1.G9 (VCCINT), U1.H8 (VCCINT), U1.J9 (VCCINT), U1.K8 (VCCINT), U1.K10 (VCCINT), U5.8 (VOUT3)
/2V5: C23.1, C26.1, C28.1, C30.1, C32.1, C34.1, C42.1, C43.1, C44.1, C45.1, J1.2 (Vccaux), R1.1, R2.2, U1.B5 (VCCO0), U1.B9 (VCCO0), U1.B13 (VCCO0), U1.E8 (VCCO0), U1.E11 (VCCAUX), U1.F5 (VCCAUX), U1.L12 (VCCAUX), U1.M6 (VCCAUX), U5.6 (VOUT2)
/3V3: C1.1, C2.1, C3.1, C4.1, C5.1, C6.1, C7.1, C8.1, C9.1, C10.1, C11.1, C12.1, C13.1, C14.1, C15.1, C16.1, C17.2, C18.2, C19.2, C22.1, C39.2, R4.1, R5.1, R6.1, R7.1, R10.1, R28.2, R29.1, R52.2, U1.D2 (VCCO3), U1.E15 (VCCO1), U1.H2 (VCCO3), U1.H12 (VCCO1), U1.J5 (VCCO3), U1.J15 (VCCO1), U1.M2 (VCCO3), U1.M9 (VCCO2), U1.N14 (IO_L01N_1/LDC2), U1.N15 (VCCO1), U1.R4 (VCCO2), U1.R8 (VCCO2), U1.R12 (VCCO2), U2.8 (VCC), U3.14 (VDD), U4.1 (E/D#), U4.4 (Vdd), U5.5 (VOUT1), U6.14 (VDD)
/5V0: C21.1, C40.1, C41.1, J2.1 (VBUS), U5.3 (VIN1/VIN2), U5.10 (VIN3)
/CLK_1MHZ: U1.N9 (IO_L11P_2/GCLK0), U4.3 (CLK)
/FPGA_DONE: R27.2, U1.T15 (DONE)
/FPGA_RST_N: R1.2, U1.A2 (/PROG)
/GND: C1.2, C2.2, C3.2, C4.2, C5.2, C6.2, C7.2, C8.2, C9.2, C10.2, C11.2, C12.2, C13.2, C14.2, C15.2, C16.2, C17.1, C18.1, C19.1, C20.2, C21.2, C22.2, C23.2, C24.2, C25.2, C26.2, C27.2, C28.2, C29.2, C30.2, C31.2, C32.2, C33.2, C34.2, C35.2, C36.2, C37.2, C38.2, C39.1, C40.2, C41.2, C42.2, C43.2, C44.2, C45.2, D1.1 (K), D2.2 (A), D3.1 (K), D4.1 (K), D5.1 (K), D6.1 (K), D7.1 (K), D8.1 (K), D9.1 (K), D10.1 (K), D11.1 (K), D12.1 (K), D13.1 (K), D14.1 (K), D15.1 (K), D16.1 (K), D17.1 (K), D18.1 (K), D19.1 (K), D20.1 (K), D21.1 (K), D22.1 (K), D23.1 (K), J1.3 (Vss), J1.5 (Vss), J1.7 (Vss), J1.9 (Vss), J1.11 (Vss), J2.5 (VSS), R3.2, R8.1, R9.1, R43.1, U1.A1 (GND), U1.A16 (GND), U1.B7 (GND), U1.B11 (GND), U1.C3 (GND), U1.C14 (GND), U1.E5 (GND), U1.E12 (GND), U1.F2 (GND), U1.F6 (GND), U1.G8 (GND), U1.G10 (GND), U1.G15 (GND), U1.H9 (GND), U1.J8 (GND), U1.K2 (GND), U1.K7 (GND), U1.K9 (GND), U1.L11 (GND), U1.L15 (GND), U1.M5 (GND), U1.M12 (GND), U1.N8 (IO_L08N_2/D4), U1.P3 (GND), U1.P14 (GND), U1.R6 (GND), U1.R10 (GND), U1.T1 (GND), U1.T16 (GND), U2.4 (GND), U3.7 (VSS), U4.2 (Vss), U5.12 (GND), U5.PAD (GND), U6.7 (VSS), U6.13 (6A)
/JTAG_TCK: J1.6 (TCK), U1.A15 (TCK)
/JTAG_TDI: J1.10 (TDI_OUT), U1.B1 (TDI)
/JTAG_TDO: J1.8 (TDO_IN), U1.B16 (TDO)
/JTAG_TMS: J1.4 (TMS), U1.B2 (TMS)
/LEVEL1_OK: R11.2, U1.C1 (IO_L01N_3)
/LEVEL1_SENSE: U1.K15 (IO_L11P_1/RHCLK0), U3.12 (6Y)
/LEVEL1_TEST: R31.1, U3.13 (6A)
/LEVEL2_OK: R12.2, U1.D1 (IO_L03P_3)
/LEVEL3_OK: R13.2, U1.D3 (IO_L02N_3)
/LEVEL3_SENSE: U1.D15 (IO_L22N_1/A21), U3.10 (5Y)
/LEVEL3_TEST: U1.D16 (IO_L22P_1/A20), U3.11 (5A)
/LEVEL4_OK: R14.2, U1.E1 (IO_L03N_3)
/LEVEL5_OK: R15.2, U1.F1 (IO_L08P_3)
/LEVEL5_SENSE: U1.H14 (IO_L14N_1/RHCLK5), U3.4 (2Y)
/LEVEL5_TEST: R38.1, U3.3 (2A)
/LEVEL6_OK: R16.2, U1.F3 (IO_L07P_3_NC_IN_50A)
/LEVEL6_SENSE: U1.D14 (IO_L23N_1/A23), U3.6 (3Y)
/LEVEL6_TEST: R39.1, U3.5 (3A)
/LEVEL7_OK: R17.2, U1.G1 (IO_L08N_3/VREF_3)
/LEVEL7_TEST_N: U1.A12 (IO_L05N_0_NC_IN_50A), U1.C12 (IO_L03P_0)
/LEVEL7_TEST_P: U1.B12 (IO_L05P_0), U1.D11 (IO_L03N_0)
/LEVEL8_OK: R18.2, U1.H1 (IO_L11N_3/LHCLK1)
/LEVEL8_SENSE: U1.H7 (IP_L13P_3), U6.2 (1Y)
/LEVEL8_TEST: U1.G2 (IO_L11P_3/LHCLK0), U6.1 (1A)
/LEVEL9_OK: R19.2, U1.H3 (IO_L12P_3/LHCLK2)
/LEVEL9_SENSE: R40.2, U1.A5 (IO_L17P_0)
/LEVEL9_TEST: R40.1, U1.A4 (IO_L18P_0)
/LEVEL10_OK: R20.2, U1.J1 (IO_L14N_3/LHCLK5)
/LEVEL10_SENSE: U1.F4 (IP_L04N_3/VREF_3), U6.4 (2Y)
/LEVEL10_TEST: R44.2, U1.G4 (IO_L07N_3_NC_IN_50A)
/LEVEL11_OK: R21.2, U1.J2 (IO_L14P_3/LHCLK4)
/LEVEL11_SENSE: U1.E4 (IP_L04P_3), U6.6 (3Y)
/LEVEL11_TEST: R45.2, U1.E3 (IO_L05P_3_NC_IN_50A)
/LEVEL12_OK: R22.2, U1.K1 (IO_L15N_3/LHCLK7)
/LEVEL12_SENSE: U1.R15 (IO_L02P_1/LDC1), U3.2 (1Y)
/LEVEL12_TEST: U1.P16 (IO_L03P_1/A0), W5.1
/LEVEL12_TEST_FLOAT: U3.1 (1A), W6.1
/LEVEL13_OK: R23.2, U1.K3 (IO_L15P_3/TRDY2/LHCLK6)
/LEVEL13_TEST_A: R36.1, U1.B3 (IO_L19N_0)
/LEVEL13_TEST_B: R37.1, U1.A3 (IO_L19P_0)
/LEVEL14_OK: R24.2, U1.M1 (IO_L20P_3)
/LEVEL15_OK: R25.2, U1.N1 (IO_L20N_3)
/LEVEL15_TEST_N: U1.A8 (IO_L12P_0/GCLK10), U1.A13 (IO_L04N_0)
/LEVEL15_TEST_P: U1.A14 (IO_L04P_0), U1.B8 (IO_L12N_0/GCLK11)
/LEVEL16_OK: R26.2, U1.N2 (IO_L22P_3)
/LEVEL16_TEST_A: R32.1, U1.T13 (IO_L18P_2/D2)
/LEVEL16_TEST_B: R33.1, U1.P13 (IO_L19N_2_NC_IN_50A)
/LEVEL17_OK: R46.2, U1.P1 (IO_L22N_3)
/LEVEL17_TEST: R43.2, U1.P7 (IO_L08P_2/D5)
/LEVEL18_OK: R47.2, U1.P2 (IO_L23N_3)
/LEVEL18_SENSE: U1.J12 (IO_L10P_1/A8), W1.1
/LEVEL18_TEST: U1.J13 (IO_L10N_1/A9), W3.1
/LEVEL19_OK: R48.2, U1.R1 (IO_L23P_3)
/LEVEL19_SENSE: R42.1, U1.J14 (IO_L14P_1/RHCLK4)
/LEVEL19_TEST: R41.2, R42.2, U1.E13 (IO_L23P_1/A22), U1.H15 (IO_L15P_1/IRDY1/RHCLK6)
/LEVEL20_OK: R49.2, U1.J3 (IO_L12N_3/IRDY2/LHCLK3)
/LEVEL21_OK: R50.2, U1.M4 (IO_L24N_3)
/LEVEL21_SENSE: U1.L5 (IP_L25P_3), U6.10 (5Y)
/LEVEL21_TEST: R35.1, U6.11 (5A)
/LEVEL22_OK: R51.2, U1.N3 (IO_L24P_3)
/LEVEL22_SENSE: U1.E14 (IO_L20P_1/A18), W2.1
/LEVEL22_TEST: U1.F13 (IO_L20N_1/A19), W4.1
/SPI_CS_N: R52.1, U1.T2 (IO_L02N_2/CSO_B), U2.1 (CS#)
/SPI_MISO: U1.T14 (IO_L20P_2/D0/DIN/MISO), U2.2 (DO/IO1)
/SPI_MOSI: U1.P10 (IO_L14N_2/MOSI/CSI_B), U2.5 (DI/IO0)
/SPI_SCK: U1.R14 (IO_L20N_2/CCLK), U2.6 (CLK)
/VBIAS: C20.1, U5.1 (EN1), U5.2 (VBIAS), U5.15 (EN3), U5.16 (EN2)
unnamed: D1.2 (A), R11.1
unnamed: D2.1 (K), R12.1
unnamed: D3.2 (A), R13.1
unnamed: D4.2 (A), R14.1
unnamed: D5.2 (A), R15.1
unnamed: D6.2 (A), R16.1
unnamed: D7.2 (A), R17.1
unnamed: D8.2 (A), R18.1
unnamed: D9.2 (A), R19.1
unnamed: D10.2 (A), R20.1
unnamed: D11.2 (A), R21.1
unnamed: D12.2 (A), R22.1
unnamed: D13.2 (A), R23.1
unnamed: D14.2 (A), R24.1
unnamed: D15.2 (A), R25.1
unnamed: D16.2 (A), R26.1
unnamed: D17.2 (A), R27.1
unnamed: D18.2 (A), R46.1
unnamed: D19.2 (A), R47.1
unnamed: D20.2 (A), R48.1
unnamed: D21.2 (A), R49.1
unnamed: D22.2 (A), R50.1
unnamed: D23.2 (A), R51.1
unnamed: R2.1, U1.D5 (IO_L20N_0/PUDC_B)
unnamed: R3.1, U1.R16 (SUSPEND)
unnamed: R4.2, U1.T12 (IO_L17P_2/INIT_B)
unnamed: R5.2, U1.N6 (IO_L04P_2/VS1)
unnamed: R6.2, U1.P5 (IO_L04N_2/VS0)
unnamed: R7.2, U1.T3 (IO_L03N_2/VS2)
unnamed: R8.2, U1.R2 (IO_L02P_2/M2)
unnamed: R9.2, U1.N4 (IO_L01P_2/M1)
unnamed: R10.2, U1.P4 (IO_L01N_2/M0)
unnamed: R28.1, U2.3 (WP#/IO2)
unnamed: R29.2, U2.7 (HOLD#/IO3)
unnamed: R30.1, U1.C16 (IO_L24P_1/A24)
unnamed: R31.2, U1.N16 (IO_L03N_1/A1)
unnamed: R32.2, U1.T4 (IO_L05P_2)
unnamed: R33.2, U1.R11 (IO_L15N_2/DOUT)
unnamed: R35.2, U1.T8 (IO_L10N_2/GCLK15)
unnamed: R36.2, U1.C8 (IO_L11P_0/GCLK8)
unnamed: R37.2, U1.D7 (IO_L16P_0)
unnamed: R38.2, U1.K16 (IO_L12P_1/RHCLK2)
unnamed: R39.2, U1.K14 (IO_L11N_1/RHCLK1)
unnamed: R41.1, U1.H16 (IO_L15N_1/RHCLK7)
unnamed: R44.1, U6.3 (2A)
unnamed: R45.1, U6.5 (3A)

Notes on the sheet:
Level-completion LED indicators Note, level 2 is intentionally backwards
IO_L03 pair intentionally swapped
FPGA decoupling
IO_L12 pair intentionally swapped
This via is level 20

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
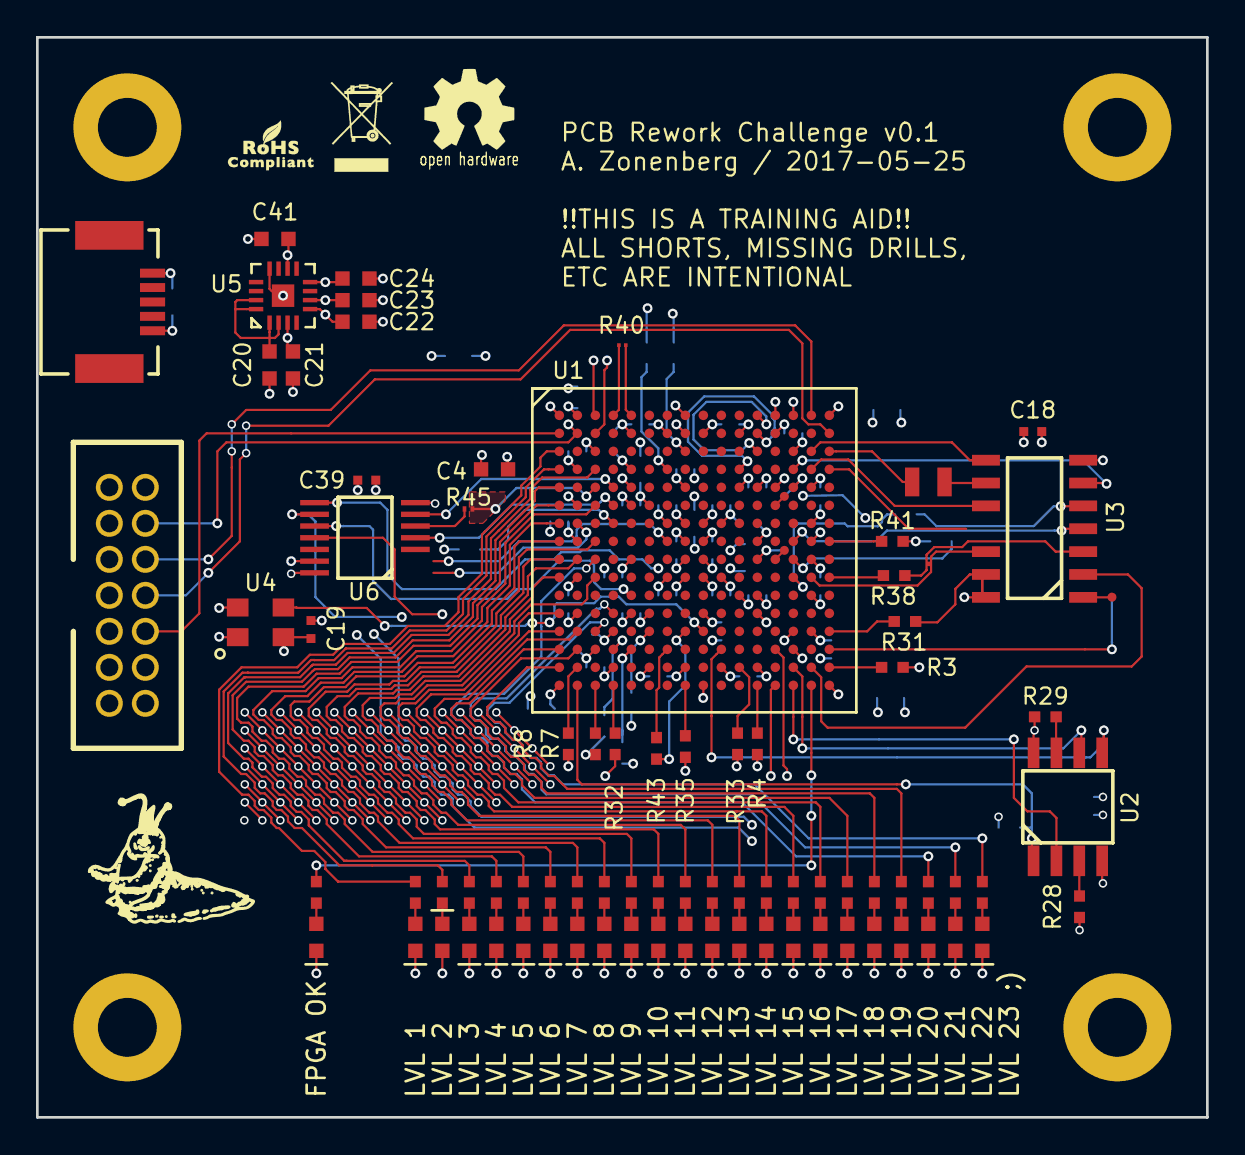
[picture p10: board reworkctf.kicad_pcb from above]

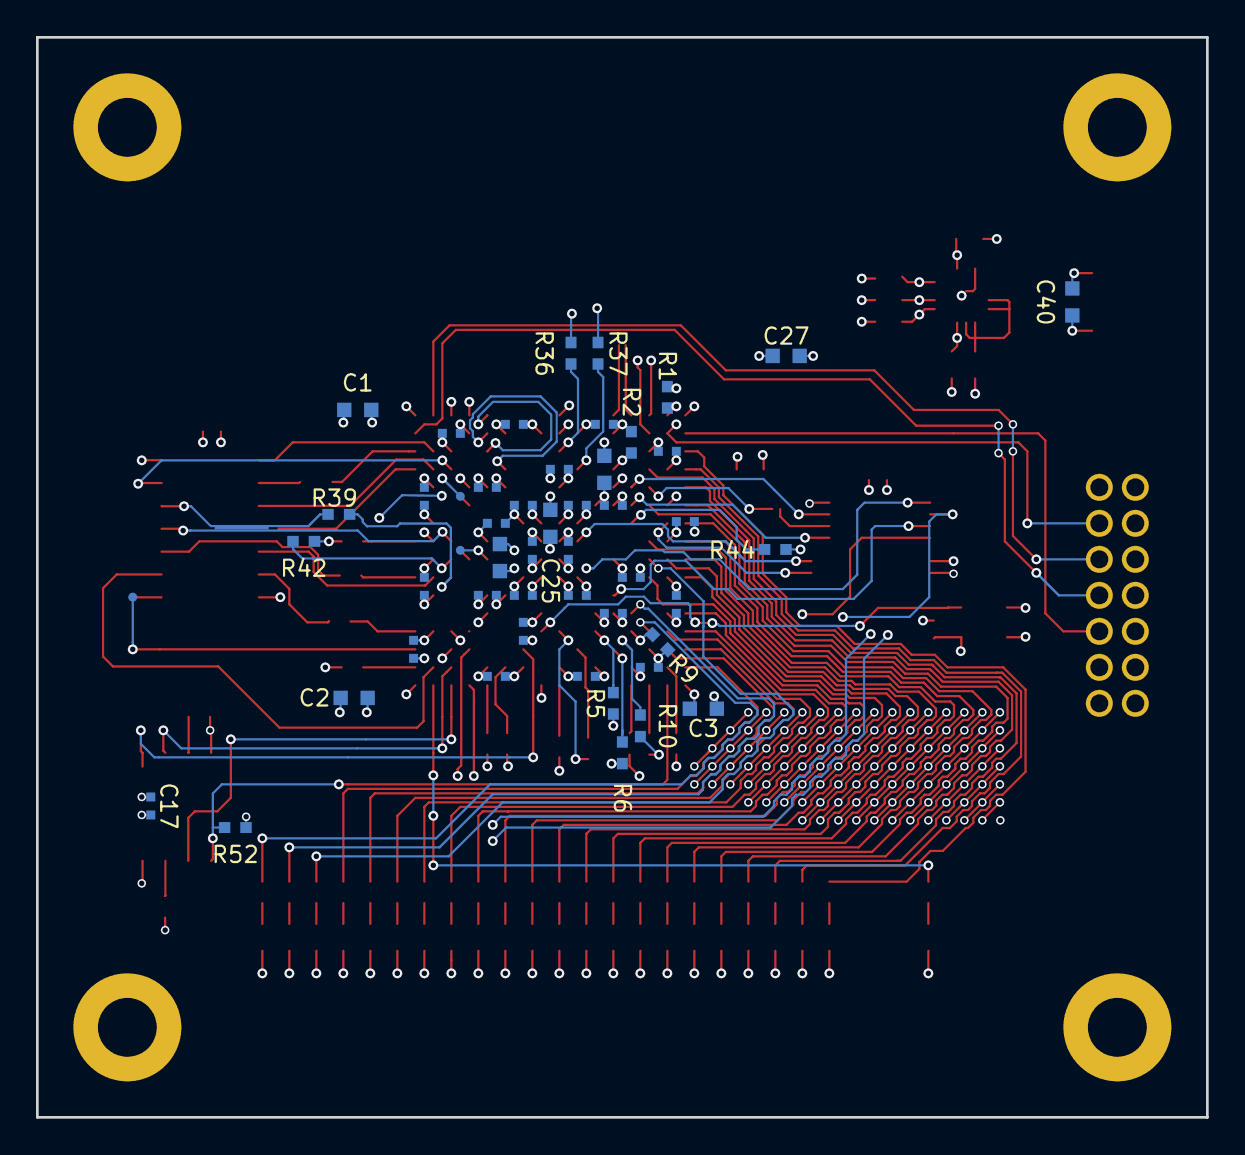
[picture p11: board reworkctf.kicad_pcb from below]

Board: 4 copper layers, 65.0 x 60.0 mm, 136 parts (51 on the bottom side), 125 nets.

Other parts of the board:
LEVEL2_SHORT, LEVEL5_SHORT, LEVEL6_SHORT: TESTPOINT_BARETRACE_150UM

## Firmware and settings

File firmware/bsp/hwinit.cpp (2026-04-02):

/***********************************************************************************************************************
*                                                                                                                      *
* reworkctf                                                                                                            *
*                                                                                                                      *
* Copyright (c) 2023-2026 Andrew D. Zonenberg and contributors                                                         *
* All rights reserved.                                                                                                 *
*                                                                                                                      *
* Redistribution and use in source and binary forms, with or without modification, are permitted provided that the     *
* following conditions are met:                                                                                        *
*                                                                                                                      *
*    * Redistributions of source code must retain the above copyright notice, this list of conditions, and the         *
*      following disclaimer.                                                                                           *
*                                                                                                                      *
*    * Redistributions in binary form must reproduce the above copyright notice, this list of conditions and the       *
*      following disclaimer in the documentation and/or other materials provided with the distribution.                *
*                                                                                                                      *
*    * Neither the name of the author nor the names of any contributors may be used to endorse or promote products     *
*      derived from this software without specific prior written permission.                                           *
*                                                                                                                      *
* THIS SOFTWARE IS PROVIDED BY THE AUTHORS "AS IS" AND ANY EXPRESS OR IMPLIED WARRANTIES, INCLUDING, BUT NOT LIMITED   *
* TO, THE IMPLIED WARRANTIES OF MERCHANTABILITY AND FITNESS FOR A PARTICULAR PURPOSE ARE DISCLAIMED. IN NO EVENT SHALL *
* THE AUTHORS BE HELD LIABLE FOR ANY DIRECT, INDIRECT, INCIDENTAL, SPECIAL, EXEMPLARY, OR CONSEQUENTIAL DAMAGES        *
* (INCLUDING, BUT NOT LIMITED TO, PROCUREMENT OF SUBSTITUTE GOODS OR SERVICES; LOSS OF USE, DATA, OR PROFITS; OR       *
* BUSINESS INTERRUPTION) HOWEVER CAUSED AND ON ANY THEORY OF LIABILITY, WHETHER IN CONTRACT, STRICT LIABILITY, OR TORT *
* (INCLUDING NEGLIGENCE OR OTHERWISE) ARISING IN ANY WAY OUT OF THE USE OF THIS SOFTWARE, EVEN IF ADVISED OF THE       *
* POSSIBILITY OF SUCH DAMAGE.                                                                                          *
*                                                                                                                      *
***********************************************************************************************************************/

/**
	@file
	@author	Andrew D. Zonenberg
	@brief	Boot-time hardware initialization
 */
#include <core/platform.h>
#include "hwinit.h"
#include <peripheral/QuadSPI.h>

/*
#include <peripheral/DWT.h>
#include <peripheral/ITM.h>
#include <embedded-utils/CoreSightRom.h>
*/

////////////////////////////////////////////////////////////////////////////////////////////////////////////////////////
// Common peripherals used by application and bootloader

/**
	@brief UART console

	Default after reset is for UART1 to be clocked by PCLK2 (APB2 clock) which is 118.75 MHz
	So we need a divisor of 1030.81
 */
UART<32, 256> g_cliUART(&USART1, 1031);

/**
	@brief MCU GPIO LEDs
 */
GPIOPin g_leds[16] =
{
	GPIOPin(&GPIOH, 13, GPIOPin::MODE_OUTPUT, GPIOPin::SLEW_SLOW),	//0
	GPIOPin(&GPIOA, 11, GPIOPin::MODE_OUTPUT, GPIOPin::SLEW_SLOW),	//1
	GPIOPin(&GPIOA, 12, GPIOPin::MODE_OUTPUT, GPIOPin::SLEW_SLOW),	//2
	GPIOPin(&GPIOG, 2, GPIOPin::MODE_OUTPUT, GPIOPin::SLEW_SLOW),	//3

	GPIOPin(&GPIOK, 2, GPIOPin::MODE_OUTPUT, GPIOPin::SLEW_SLOW),	//4
	GPIOPin(&GPIOA, 8, GPIOPin::MODE_OUTPUT, GPIOPin::SLEW_SLOW),	//5
	GPIOPin(&GPIOC, 9, GPIOPin::MODE_OUTPUT, GPIOPin::SLEW_SLOW),	//6
	GPIOPin(&GPIOG, 8, GPIOPin::MODE_OUTPUT, GPIOPin::SLEW_SLOW),	//7

	GPIOPin(&GPIOC, 6, GPIOPin::MODE_OUTPUT, GPIOPin::SLEW_SLOW),	//8
	GPIOPin(&GPIOG, 6, GPIOPin::MODE_OUTPUT, GPIOPin::SLEW_SLOW),	//9
	GPIOPin(&GPIOG, 5, GPIOPin::MODE_OUTPUT, GPIOPin::SLEW_SLOW),	//10
	GPIOPin(&GPIOG, 4, GPIOPin::MODE_OUTPUT, GPIOPin::SLEW_SLOW),	//11

	GPIOPin(&GPIOK, 1, GPIOPin::MODE_OUTPUT, GPIOPin::SLEW_SLOW),	//12
	GPIOPin(&GPIOG, 3, GPIOPin::MODE_OUTPUT, GPIOPin::SLEW_SLOW),	//13
	GPIOPin(&GPIOK, 0, GPIOPin::MODE_OUTPUT, GPIOPin::SLEW_SLOW),	//14
	GPIOPin(&GPIOJ, 11, GPIOPin::MODE_OUTPUT, GPIOPin::SLEW_SLOW)	//15
};

/**
	@brief Microkvs and firmware storage for the MCU

	Initialize the QSPI block assuming 128 Mbits to start
	QSPI kernel clock defaults to HCLK3 which is 237.5 MHz
	Divide by 4 gives 59.375 MHz which should be fairly safe to start
 */
QuadSPI_SpiFlashInterface g_flashQspi(&_QUADSPI, 128 * 1024 * 1024, 4);

////////////////////////////////////////////////////////////////////////////////////////////////////////////////////////
// Task tables

etl::vector<Task*, MAX_TASKS>  g_tasks;
etl::vector<TimerTask*, MAX_TIMER_TASKS>  g_timerTasks;

////////////////////////////////////////////////////////////////////////////////////////////////////////////////////////
// Do other initialization

void InitITM();
bool InitQSPI();

void BSP_InitTasks();

void GradeChallenges();
void GradeChallenge1();
void GradeChallenge2();
void GradeChallenge3();
void GradeChallenge4();
void GradeChallenge5();
void GradeChallenge6();
void GradeChallenge7();
void GradeChallenge8();
void GradeChallenge9();
void GradeChallenge10();
void GradeChallenge11();
void GradeChallenge12();
void GradeChallenge13();
void GradeChallenge14();
void GradeChallenge15();
void GradeChallenge16();
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

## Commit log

2017-05-24 Finished initial work on reworkctf schematic and documentation
    [reworkctf.sch]
2017-05-24 Initial work on layout
    [reworkctf.kicad_pcb, reworkctf.sch]
2017-05-24 Continued initial layout
    [reworkctf.kicad_pcb, reworkctf.sch]
2017-05-24 Continued work on initial layout
    [reworkctf.kicad_pcb, reworkctf.sch]
2017-05-24 Began work on active mesh
    [reworkctf.kicad_pcb, reworkctf.sch]
2017-05-26 Finished initial work on rework challenge board
    [reworkctf.kicad_pcb, reworkctf.sch]
2017-05-26 Removed soldermask openings on short circuits
    [reworkctf.kicad_pcb]
2026-03-16 Initial skeleton of v2 design
    [psu.kicad_sch, reworkctf-v2.kicad_pcb, reworkctf-v2.kicad_sch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]
2026-03-17 Finished initial MCU layout, need to actually add challenges
    [psu.kicad_sch, reworkctf-v2.kicad_pcb, reworkctf-v2.kicad_sch]
2026-03-17 Got up to challenge 8
    [psu.kicad_sch, reworkctf-v2.kicad_pcb, reworkctf-v2.kicad_sch]
2026-03-17 Added challenge 7 with lifted pad on the soic
    [reworkctf-v2.kicad_pcb]
2026-03-17 Added challenge 9 with diffpair polarity swap on inner layer
    [reworkctf-v2.kicad_pcb, reworkctf-v2.kicad_sch]
2026-03-18 Added challenges 10 and 11 for vias
    [reworkctf-v2.kicad_pcb, reworkctf-v2.kicad_sch]
2026-03-18 Added SM-2 challenge, shrunk overall PCB footprint a bunch
    [reworkctf-v2.kicad_pcb, reworkctf-v2.kicad_sch]
2026-03-18 Added challenge 15 (missing pullup)
    [reworkctf-v2.kicad_pcb, reworkctf-v2.kicad_sch]
2026-03-18 Initial work on "free play area" sandbox
    [free-play.kicad_sch, reworkctf-v2.kicad_pcb, reworkctf-v2.kicad_sch]
2026-03-18 Added more inner layer test features to free play area
    [free-play.kicad_sch, reworkctf-v2.kicad_pcb, reworkctf-v2.kicad_sch]
2026-03-19 Added strap via to wrong net. Should be ready to order, I think
    [reworkctf-v2.kicad_pcb, reworkctf-v2.kicad_sch]
2026-03-19 Final version of v2 board including export settings
    [reworkctf-v2.kicad_pcb]
